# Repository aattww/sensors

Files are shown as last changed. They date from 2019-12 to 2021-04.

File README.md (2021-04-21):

# Summary

This project consists of simple Atmel ATmega328P based nodes utilizing HopeRF LoRa RFM95W/RFM96W radios. Battery-powered nodes measure temperature, humidity and barometric pressure, depending on connected hardware. Externally powered pulse type nodes count pulses from different utility meters and also connect to Kamstrup Multical energy meters. Gateway receives and collects these measurements from the sensor nodes and can be accessed by serial communication using Modbus RTU protocol via either two-wire RS-485 or common 3.3 volt UART. This enables interfacing with many DIY home automation systems such as [Domoticz](https://www.domoticz.com/), [Home Assistant](https://www.home-assistant.io/) and [openHAB](https://www.openhab.org/). Sensors uses custom circuit boards but is programmed with Arduino IDE.



This project is a complete package: it includes both hardware designs and software. *Schematics* contains PCB designs so you can manufacture or order PCBs from a factory and solder the nodes. Software is ready to be uploaded as it is. If you do not want to use the hardware designs provided, you should be able to use, for example, Arduino Pro Minis with protoboards instead. Browse through the .inos and the schematics to find out pin definitions. Remember to take into account battery usage if using Pro Minis or other "full size" Arduinos. Also remember that the components used are mostly 3.3 volt tolerant only, so using a 5 volt Uno requires level shifting.

Skip directly to [Instructions](#instructions), although I strongly recommend reading the whole readme first.

# Table of Contents

* [External requirements](#external-requirements)
  * [Libraries](#libraries)
  * [Hardware package (core)](#hardware-package-core)
* [Gateway](#gateway)
  * [Modbus registers](#modbus-registers)
    * [Gateway specific registers](#gateway-specific-registers)
    * [Battery powered node specific registers](#battery-powered-node-specific-registers)
    * [Pulse node specific registers](#pulse-node-specific-registers)
    * [Pulse node with Kamstrup Multical 602 energy meter specific registers](#pulse-node-with-kamstrup-multical-602-energy-meter-specific-registers)
* [Node types](#node-types)
  * [Battery](#battery)
    * [Supported sensors](#supported-sensors)
  * [Pulse](#pulse)
  * [Pulse with Kamstrup Multical 602 energy meter](#pulse-with-kamstrup-multical-602-energy-meter)
* [Radios](#radios)
* [Schematics and PCB](#schematics-and-pcb)
  * [BOM](#bom)
    * [Gateway / Pulse / Pulse with Kamstrup Multical](#gateway--pulse--pulse-with-kamstrup-multical)
    * [Battery](#battery-1)
  * [LEDs](#leds)
    * [Gateway](#gateway-1)
    * [Battery](#battery-2)
    * [Pulse / Pulse with Kamstrup Multical](#pulse--pulse-with-kamstrup-multical)
  * [Headers, terminals and buttons](#headers-terminals-and-buttons)
    * [Gateway](#gateway-2)
    * [Battery](#battery-3)
    * [Pulse / Pulse with Kamstrup Multical](#pulse--pulse-with-kamstrup-multical-1)
* [Instructions](#instructions)
* [Version history](#version-history)

# External requirements

Sensors requires a few external components to work: libraries provide functions for radio communications and connected sensors while hardware package handles needed fuses to work with custom boards used by Sensors. Follow carefully especially the instructions regarding RadioHead and Cryptography libraries, as these require a couple of underlying changes.

## Libraries

**RadioHead Packet Radio library for embedded microprocessors** provides support for RFM95W/RFM96W radios (and many others as well). Download from [airspayce.com](https://www.airspayce.com/mikem/arduino/RadioHead/). After extracting the library to your Arduino IDE libraries folder you will have to do one adjustment. In the beginning of *RadioHead/RH_RF95.h* change line  
`#define RH_RF95_FIFO_SIZE 255`  
to  
`#define RH_RF95_FIFO_SIZE 64`  
Communication will not work without this change. You also risk running out of SRAM without this adjustment.

**Arduino Cryptography Library** includes support for encryption. If you do not plan to encrypt traffic, you will not need this library. Download from [github.com](https://github.com/rweather/arduinolibs). You will need to download the ZIP and extract contents of *libraries* to your Arduino IDE libraries folder. Also remember to uncomment the following line at the very end of *RadioHead/RadioHead.h* to enable encryption:  
`//#define RH_ENABLE_ENCRYPTION_MODULE`  
You will also need to disable watchdog entropy harvesting by commenting out the following line at the beginning of *Crypto/RNG.cpp* because watchdog timer is already used by battery powered nodes:  
`#define RNG_WATCHDOG 1      // Harvest entropy from watchdog jitter.`  
If you are overwhelmed by all this, you may just want not to enable encryption at all. After all, Sensors is not exactly high security system anyway.

**LowPowerLab SI7021** library is needed to work with Silicon Labs Si7021 temperature and humidity sensor. Download from [github.com](https://github.com/LowPowerLab/SI7021).

**SparkFun BME280 Arduino Library** interfaces with Bosch Sensortech BME280 temperature, humidity and barometric pressure sensor. Documentation at [github.com](https://github.com/sparkfun/SparkFun_BME280_Arduino_Library). Install using Arduino IDE Library Manager.

## Hardware package (core)

Sensors uses a bit different hardware design than regular Arduino boards. For example, battery operated nodes run on internal 1 MHz clock and gateway uses external 8 MHz crystal. They also lack bootloader (although you could use it, hardware just doesn't provide serial pins to burn new firmware using bootloader anyway). Instead, program is flashed using ICSP through ISP header.

You could set the necessary fuses manually but it is considerably easier to just use a ready-made hardware package. MCUdude has a nice core specifically to do this. Download MCUdude's MiniCore from [github.com](https://github.com/MCUdude/MiniCore).

# Gateway

Gateway collects data from nodes and acts as an relay to a [Modbus](https://en.wikipedia.org/wiki/Modbus) network. By using Maxim Integrated MAX3485 RS-485 transceiver gateway can be connected to an existing RS-485 Modbus RTU network as a slave. Omitting the transceiver provides a direct TTL serial port. This can be accessed with, for example, another Arduino board, FTDI chip or connected directly to a Raspberry Pi. Regardless of the physical connection, gateway is accessed using Modbus protocol. Gateway requires regulated 3.3 volts or (unregulated) 5-12 volts DC power supply. In addition, gateway has three pulse inputs (pulse values are periodically saved to EEPROM and restored on power-up), one of which can be used as an NTC thermistor input. These inputs are also accessible via Modbus.

One drawback of Modbus protocol is that a slave can not inform the master of new messages. For this, pulse 2 can be enabled to work as an external interrupt. This pin behaves like an emulated open collector output (external high state voltage is limited to 3.3 volts, however). The pin will be pulled to ground when a message is received either from an *important* node or any node, depending on the gateway settings. After Modbus read has been done, this pin will be set back to high impedance state.

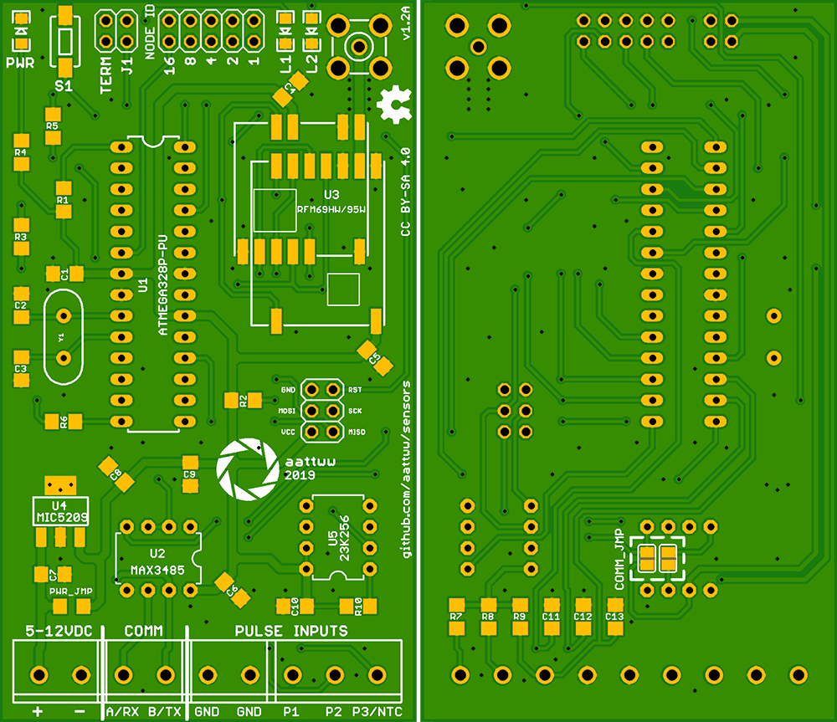
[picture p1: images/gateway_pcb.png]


**Warning:** UART serial port is 3.3 volts, so don't connect it to a 5 volt system.

Why Modbus? Modbus is an easy to use and integrate protocol for this kind of data transfer. Although it is old and somewhat limited in features, it still provides all the necessary things and is widely used in industry. Libraries to access it exist for more or less every platform. Also, most DIY home automation systems ([Home Assistant](https://www.home-assistant.io/), [Domoticz](https://www.domoticz.com/) and [openHAB](https://www.openhab.org/) to name a few) have Modbus support.

## Modbus registers

Registers can be accessed using either function code 3 (read holding registers) or 4 (read input registers). Both return the same register values. Note that registers not defined can not be read. For example, trying to read registers 21-99 or 108-199 will return *illegal data address exception*.

### Gateway specific registers

| Address | Number | Name | Type / Unit | Notes |
| --- | --- | ---- | ---- | ----- |
| 0 | 30001  | Modbus errors (CRC failed or corrupted) | Counter |  |
| 1 | 30002  | Modbus overflown frames | Counter |  |
| 2 | 30003  | Modbus illegal function reads | Counter |  |
| 3 | 30004  | Modbus illegal address reads | Counter |  |
| 4 | 30005 | Modbus frames received | Counter |  |
| 5 | 30006  | Modbus frames sent | Counter |  |
| 6 | 30007  | Nodes during last hour | Counter |  |
| 7 | 30008  | Nodes during last 12 hours | Counter |  |
| 8 | 30009  | Nodes during last 24 hours | Counter |  |
| 9 | 30010  | At least one node low on battery | Boolean |  |
| 10 | 30011  | Gateway out of memory | Boolean |  |
| 11 | 30012  | Gateway uptime | Hour | |
| 12 | 30013  | Firmware version | | 8 MSB = major, 8 LSB = minor |
| 13 | 30014  | Status |  | See below for bits. |
| 14 | 30015  | Pulse 1 | Counter | 32 bit |
| 16 | 30017  | Pulse 2 | Counter | 32 bit |
| 18 | 30019  | Pulse 3 / Temperature | Counter / °C | 32 bit |
| 20 | 30021  | Last received node ID |  |  |

Status register bits (from LSB to MSB):
* Bit 0 **External SRAM:** *1* if gateway has external SRAM, *0* if using internal SRAM. Affects maximum number of nodes, see notes in [Schematics and PCB](#schematics-and-pcb).
* Bit 1-15 **Reserved**

### Battery powered node specific registers

First address is *node id * 100*. For example, this table shows addresses for a node id 1. Similarly, measurements for node id 2 start at address 200, and so on.

| Address | Number | Name | Type / Unit | Notes |
| --- | --- | ---- | ---- | ----- |
| 100 | 30101  | Last received | Minute | When was node last seen. |
| 101 | 30102  | Battery voltage | mV | Current battery voltage. |
| 102 | 30103  | Transmit power | % | Relative transmit power. |
| 103 | 30104  | Transmit interval | Minute | How often the node transmits at least. |
| 104 | 30105  | Header |  | Only 8 LSB, debug data. See below for bits. |
| 105 | 30106  | Temperature | °C | ×10 |
| 106 | 30107  | Relative humidity | RH% | ×10. **Only if node has Si7021 or BME280.** |
| 107 | 30108  | Barometric pressure / Temperature | hPa / °C | ×10. **Pressure if node has BME280, temperature if node has both Si7021 and NTC.** |

Header register bits (from LSB to MSB):
* Bit 0-2 **Node type:** Internal definiton of the node type.
* Bit 3 **Reserved**
* Bit 4 **Battery-powered:** *1* if node is battery-powered, *0* if powered externally.
* Bit 5 **Important:** *1* if node has declared itself important, *0* if not.
* Bit 6-7 **Reserved**

### Pulse node specific registers

First address is *node id * 100*. For example, this table shows addresses for a node id 2. Similarly, measurements for node id 3 start at address 300, and so on.

| Address | Number | Name | Type / Unit | Notes |
| --- | --- | ---- | ---- | ----- |
| 200 | 30201  | Last received | Minute | When was node last seen. |
| 201 | 30202  | Transmit power | % | Relative transmit power. |
| 202 | 30203  | Transmit interval | Minute | How often the node transmits at least. |
| 203 | 30204  | Header |  | Only 8 LSB, debug data. See below for bits. |
| 204 | 30205  | Pulse 1 | Counter | 32 bit |
| 206 | 30207  | Pulse 2 | Counter | 32 bit |
| 208 | 30209  | Pulse 3 / Temperature | Counter / °C | 32 bit |

Header register bits (from LSB to MSB):
* Bit 0-2 **Node type:** Internal definiton of the node type.
* Bit 3 **Reserved**
* Bit 4 **Battery-powered:** *1* if node is battery-powered, *0* if powered externally.
* Bit 5 **Important:** *1* if node has declared itself important, *0* if not.
* Bit 6-7 **Reserved**

### Pulse node with Kamstrup Multical 602 energy meter specific registers

First address is *node id * 100*. For example, this table shows addresses for a node id 3. Similarly, measurements for node id 4 start at address 400, and so on.

| Address | Number | Name | Type / Unit | Notes |
| --- | --- | ---- | ---- | ----- |
| 300 | 30301  | Last received | Minute | When was node last seen. |
| 301 | 30302  | Transmit power | % | Relative transmit power. |
| 302 | 30303  | Transmit interval | Minute | How often the node transmits at least. |
| 303 | 30304  | Header |  | Only 8 LSB, debug data. See below for bits. |
| 304 | 30305  | Pulse 1 | Counter | 32 bit |
| 306 | 30307  | Pulse 2 | Counter | 32 bit |
| 308 | 30309  | Pulse 3 / Temperature | Counter / °C | 32 bit |
| 310 | 30311  | Heat energy | kWh | 32 bit |
| 312 | 30313  | Actual flow | l/h | 32 bit |
| 314 | 30315  | Volume | m³ | ×100. 32 bit |
| 316 | 30317  | Actual power | kW | ×10. 32 bit |
| 318 | 30319  | Actual t₁ | °C | ×100. 32 bit |
| 320 | 30321  | Actual t₂ | °C | ×100. 32 bit |

Header register bits (from LSB to MSB):
* Bit 0-2 **Node type:** Internal definiton of the node type.
* Bit 3 **Reserved**
* Bit 4 **Battery-powered:** *1* if node is battery-powered, *0* if powered externally.
* Bit 5 **Important:** *1* if node has declared itself important, *0* if not.
* Bit 6-7 **Reserved**

# Node types

Sensors includes two main types of nodes: battery and pulse. Battery-powered low-power nodes monitor temperature, humidity and pressure. Pulse type nodes are externally powered and count pulses from utility meters. Pulse nodes also support connecting one NTC thermistor for temperature monitoring and RS-485 Modbus RTU. The latter enables the node to be connected to a Kamstrup Multical 602 energy meter.

## Battery

Battery powered sensors provide simple nodes to monitor temperature, humidity and barometric pressure. These nodes operate on two normal 1.5 volt AA alkaline batteries. If longer lifetime is needed or if node is placed in cold environment, more expensive 1.5 volt AA-size lithium batteries can also be used.

**Warning:** Hardware provides no reverse voltage protection in order to conserve power and to keep number of parts minimal, so **make sure to observe polarity when inserting batteries or you will destroy the node**.

Nodes spend most of the time sleeping, only to wake up to take measurements and send values to gateway. Frequency can be controlled through settings at the beginning of the code file. In threshold mode, nodes wake up periodically and take measurements. If values differ enough from previously sent ones, a message is sent. If not, nodes return to sleep. However, there is a specific force time controlling how often a new message is sent at least regardless of threshold. If a node is not operating in threshold mode, it will send a message every time it wakes up.

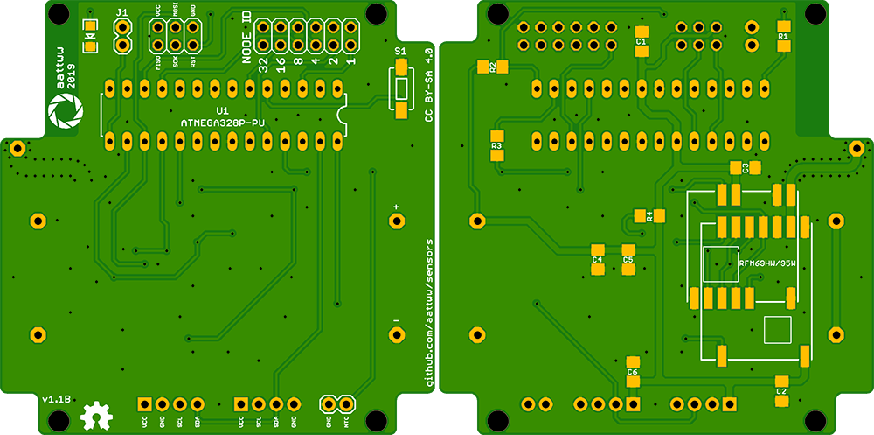
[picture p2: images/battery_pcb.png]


### Supported sensors

Nodes support three types of sensors: Silicon Labs Si7021, Bosch Sensortech BME280, and a common NTC thermistor. The first one has temperature and humidity, the second one adds barometric pressure, and the latter provides only temperature. A node can have only one kind of sensor, or as a special case both Si7021 and NTC at the same time. PCB provides footprints for all, and the exact type is defined in runtime. That is, every node is flashed with the same software and it checks at bootup what kind of sensor configuration is connected.

**Si7021** sensors can be bought as breakout boards from eBay and similar places for a couple of dollars. When buying the sensor, get one that does not include voltage regulator and I2C level shifting. Battery powered nodes operate on 3.3 volts so Si7021 can be fed directly. Not having (unnecessary) regulator saves battery power. For example, [this one](https://www.ebay.com/itm/SMD-MINI-Si7021-Temperature-and-Humidity-Sensor-I2C-Interface-for-Arduino/264394330907) is recommended, while [this one](https://www.ebay.com/itm/Si7021-Industrial-High-Precision-Humidity-Sensor-I2C-Interface-for-Arduino/201539848414) is not.

**BME280** sensors are also available in eBay, Aliexpress and similar as breakout boards. They are a bit more expensive. These seem not to be available without the onboard regulator, so if you want to lower power consumption, your only option is to remove the regulator. Example image of a removed regulator [shown here](images/bme280.jpg). [This sensor](https://www.ebay.com/itm/Breakout-Temperature-Humidity-Barometric-Pressure-BME280-Digital-Sensor-Module/401000227934), for example, has been used successfully.

**Note:** Chinese sellers sometimes mix the BME280 with earlier and less featured BMP280. Be careful when buying the sensor. Info about this for example [here](https://goughlui.com/2018/08/05/note-bosch-sensortec-bmp280-vs-bme280-sensor-confusion/) and [here](https://www.meteocercal.info/forum/Thread-Bosch-Sensortec-BMP280-vs-BME280-Sensor-Confusion).

**NTC thermistors** can be purchased from the same places as the other sensors. When buying thermistors, make sure you get three necessary values: *nominal resistance*, *nominal temperature* and *beta coefficient*. For example, [this thermistor](https://www.ebay.com/itm/5PCS-1m-NTC-Thermistor-accuracy-temperature-sensor-10K-1-3950-Waterproof-Probe/311572298670) has been successfully used and works with the default values.

## Pulse

Pulse type nodes are intended to measure pulses from a water, electricity, gas or other kind of meter with pulse output. Nodes have three pulse inputs, one of which can be used as an NTC thermistor input instead of a pulse input. Pulse inputs are pulled high internally by microcontroller or with optional external resistors, and connected meter pulls it low to ground. Pulse values are periodically saved to EEPROM and restored on power-up. Pulse nodes require either regulated 3.3 volts or (unregulated) 5-12 volts DC power supply. They use the same PCB as the gateway.

## Pulse with Kamstrup Multical 602 energy meter

These nodes are regular pulse nodes with added support for Kamstrup Multical 602 energy meter. Node is connected by RS-485 to a Multical 602 energy meter and periodically reads certain values from the meter. See Modbus register listing above for these values.

**Note:** Multical 602 seems to be discontinued and replaced by Multical 603. According to datasheet, Multical 603 supports the same Modbus registers as the old 602. Therefore nodes should work with newer 603s but this is untested.

**Protip:** Using this node as an example, it should be quite easy to connect some other kind of Modbus RTU capable device to a Pulse type node and adjust code accordingly. This way you can read any other Modbus meters or devices via Sensors nodes.

# Radios

Sensors utilize HopeRF RFM95W and RFM96W LoRa radios. RFM95W is for 868/915 MHz and RFM96W for 433 MHz. These are cheap low power radios with very good range. Battery nodes use wire or helical antennas, while gateway and pulse nodes have SMA connectors for better performing antennas. Please consider local regulations when choosing frequency range, bandwidth, transmit power and other radio related settings. Nodes automatically adjust transmit power to the lowest possible level.

Attainable range depends greatly on numerous things but personally I have easily achieved over one kilometer through a reinforced concrete wall and a metal facade. This was between a gateway with a dipole SMA antenna and a battery node with helical antenna. The same setup also reached over 200 meters through buildings in a more built environment. However, as with wireless communication in general, your results will vary.

**Note:** On the PCB there is footprint for older HopeRF RFM69HW radio as well. It should work, but it has not been tested and there is currently no support in software for this. Feel free to create a new branch and implement it.

# Schematics and PCB

Following is the table of bill of materials. Not all components are needed, see the notes below for these parts. Majority of the SMD components are 1206 package for easier hand soldering. Gateways and pulse nodes share the same PCB.

Some notes:
* MAX3485 transceiver is needed only if you connect the gateway to an existing RS-485 network. If you use direct UART it is not needed. In this case, remember to also short *COMM_JMP* at the bottom.
* External pull-up resistors are probably not needed in most cases as internal ones in ATmega328P are usually adequate. However, if you are connecting NTC thermistor to pulse 3, remember to solder the 10 kOhm series resistor.
* Pulse smoothing capacitors are optional. Use them if you encounter erroneous pulses, ie. too many pulses are counted. For example, I had a [rain gauge](https://www.amazon.co.uk/dp/B00QDMBXUA) connected to a pulse input with a rather long cable (about 10 meters running next to mains power supply for part of length). Extra pulses were counted even when no rain had fallen. Adding a 10 uF capacitor removed these wrong measures.
* MIC5209 regulator makes it possible to power the gateway/pulse node with DC voltage between 5-12 volts (technically up to 16 volts but it might start to get warm). If you can supply the board with regulated 3.3 volts, you can omit the regulator. In this case, also short the *PWR_JMP*.
* The Microchip 23K256 SRAM chip is optional. Without it, gateway falls back using its internal SRAM. However, this severely limits the amount of nodes. With the 23K256 gateway supports 100 nodes regardless of type, without it only 10. This varies by node type, however. For example, without external SRAM gateway supports 10 battery nodes, or 5 pulse nodes, or 6 battery nodes plus 2 pulse nodes.
* SMA connector can be omitted and replaced with a wire or a helical antenna if these smaller gain antennas are sufficient. You can also, with some very careful alignment, solder a u.FL connector on to the SMA connector footprint. This allows using a u.FL to SMA pigtail to move the actual SMA connector away.

I have successfully ordered PCBs from Seeed Studio. You can get boards for 10 gateways/pulse nodes and 10 battery nodes for $9.80 plus postage. Of course any prototype PCB factory will work. PCBs are designed not to have any tight spacings or need for strict tolerances. For gateway and pulse node, select 1.6mm thickness (the enclosure will hold the PCB better). With battery nodes, boards can be thinner (for example 1.2mm works well). Other options should be okay with defaults.

Boards are designed to fit the enclosures mentioned in the table. [Bud Industries DMB-4771](https://www.budind.com/view/Plastic+Boxes/DIN+Rail+Mount+Multi-Board+Box) is a 35mm DIN rail mounted box, while [Supertronic PP42](http://www.supertronic.com/en/cajas_de_plastico/sensors/29/pp42/50) is a simple wall mounted enclosure (use double-sided tape). In the *schematics* folder there is also *AP9_holder.stl* which is a 3D model of a simple holder to fix a battery node into an [ABB AP9 junction box](https://new.abb.com/products/2TKA140012G1/ap9-junction-box-ip65). This is especially handy if you install a node outside and have access to a 3D printer. You will need two holders and a set of small screws. You will also need to have a way to make the box rain-proof but still let humidity and temperature in. Poking some holes into membrane cable entries is one way, or if you want to go professional, use a sintered protective cover. [This](https://www.ebay.com/itm/Protective-Cover-SHT10-SHT20-Soil-Temperature-Humidity-Moisture-Sensor-Shell/173940209491) has been proven to work: a BME280 breakout board will *just* fit inside if you solder wires to the board as [shown here](images/bme280.jpg). Remember to wrap the breakout board (but not the sensor itself) with some insulating tape or use heat shrink to prevent short circuits. [This image](images/si7021_wired.jpg) shows an Si7021 breakout board prepared for outdoor sensor use. You will also need to drill off the plastic inside with the connectors of the protective cover. Use some imagination here. A ready-made weatherproofed sensor looks something like [this](images/weatherproof_node.jpg). Connecting an NTC thermistor with sufficiently long wire will make a nice water temperature node as shown [here](images/water_temperature_node.jpg).

## BOM

### Gateway / Pulse / Pulse with Kamstrup Multical

| Part | Value | Device | Package | Type | Notes |
| ---- | ----- | --- | --- | ---- | ----- |
| C1 | 100 nF | Decoupling capacitor | 1206 | Ceramic | |
| C2 | 22 pF | Crystal capacitor | 1206 | Ceramic | |
| C3 | 22 pF | Crystal capacitor | 1206 | Ceramic | |
| C4 | 100 nF | Decoupling capacitor | 1206 | Ceramic | Used only with RFM95W / RFM96W. |
| C5 | 100 nF | Decoupling capacitor | 1206 | Ceramic | Used only with RFM69HW. |
| C6 | 100 nF | Decoupling capacitor | 1206 | Ceramic | Used only with U2 (MAX3485). |
| C7 | 1 uF | Power input capacitor | 1206 | Tantalum | |
| C8 | 1 uF | Power output capacitor | 1206 | Tantalum | |
| C9 | 10 uF | Power output capacitor | 1206 | Ceramic | |
| C10 | 100 nF | Decoupling capacitor | 1206 | Ceramic | Used only with 23K256. |
| C11 | Depends | Pulse 3 smoothing capacitor | 1206 | Ceramic | Use if erroneous pulses are counted. |
| C12 | Depends | Pulse 2 smoothing capacitor | 1206 | Ceramic | Use if erroneous pulses are counted. |
| C13 | Depends | Pulse 1 smoothing capacitor | 1206 | Ceramic | Use if erroneous pulses are counted. |
| R1 | 10 kOhm | Reset pull-up resistor | 1206 | | |
| R2 | 10 kOhm | Radio slave select pull-up resistor | 1206 | | |
| R3 | 120 Ohm | RS-485 termination resistor | 1206 | | Used only with U2 (MAX3485). |
| R4 | Depends | Power LED resistor | 1206 | | Select value based on LED in use. |
| R5 | Depends | Activity LED resistor | 1206 | | Select value based on LED in use. |
| R6 | Depends | Serial activity LED resistor | 1206 | | Select value based on LED in use. |
| R7 | Depends / 10 kOhm | Pulse 3 pull-up / NTC series resistor | 1206 | | Use if ATmega328P internal pull-up resistor is not strong enough, or NTC is to be used. |
| R8 | Depends | Pulse 2 pull-up resistor | 1206 | | Use if ATmega328P internal pull-up resistor is not strong enough. |
| R9 | Depends | Pulse 1 pull-up resistor | 1206 | | Use if ATmega328P internal pull-up resistor is not strong enough. |
| R10 | 10 kOhm | SRAM slave select pull-up resistor | 1206 | | Used only with 23K256. |
| D1 | | Serial activity LED | 1206 | | |
| D2 | | Power LED | 1206 | | |
| D3 | | Activity LED | 1206 | | |
| Y1 | 8 MHz | HC-49US 8 MHz crystal | | | |
| S1 | | Momentary push button | 3x6 mm | | For example, [this one](https://www.ebay.com/itm/100-Pcs-3x6x2-5mm-Momentary-Tact-SMD-SMT-Push-Button-Micro-Switch-2-Pin/272961316148). |
| X1 | | SMA connector | | | For example, [this one](https://www.ebay.com/itm/End-Launch-PCB-Mount-SMA-Female-Plug-Straight-RF-Connector-Adapter-10-Pcs-R7Z6-/253508669169). |
| Header | | ISP programming header | 2x3, 0.1" pitch | | |
| Header | | Node ID selection header | 2x5, 0.1" pitch | | |
| Header | | RS-485 terminate and J1 header | 2x2, 0.1" pitch | | |
| Screw terminals | | Power, serial, pulse grounds, pulse inputs | 3x2 + 1x3, 5.08mm pitch | | For example, [two terminal](https://www.ebay.com/itm/20PCS-KF301-2P-2-Pin-Plug-in-Terminal-Block-Connector-5-08mm-Pitch-Through-Hole/381374540897) and [three terminal](https://www.ebay.com/itm/10pcs-KF301-3P-5-08mm-Blue-Connect-Terminal-Blue-Screw-Terminal-Connector/201415082308). |
| PWR_JMP | | Solder jumper | 1206 | | Short or use a zero-ohm resistor if not using U4, i.e. board is provided external regulated 3.3 volts. |
| COMM_JMP | | Solder jumper | | | Short if not using U2, i.e. direct UART is used. |
| U1 | | Atmel ATmega328P microcontroller | DIP-28 | | Preferably use a socket. |
| U2 | | Maxim MAX3485 RS-485 transceiver | DIP-8 | | Preferably use a socket. Use only if connected to an RS-485 network. |
| U3 | | HopeRF RFM95W/RFM96W/RFM69HW | | | |
| U4 | | Microchip MIC5209-3.3 regulator | SOT-223 | | Optional (see notes above). |
| U5 | | Microchip 23K256 SRAM | DIP-8 | | Optional (see notes above). Preferably use a socket. |
| Enclosure | | Bud Industries DMB-4771 | | | |

### Battery

| Part | Value | Device | Package | Type | Notes |
| ---- | ----- | --- | --- | ---- | ----- |
| C1 | 100 nF | Decoupling capacitor | 1206 | Ceramic | |
| C2 | 100 nF | Decoupling capacitor | 1206 | Ceramic | Used only with RFM69HW. |
| C3 | 100 nF | Decoupling capacitor | 1206 | Ceramic | Used only with RFM95W / RFM96W. |
| C4 | 100 nF | Power smoothing capacitor | 1206 | Ceramic | |
| C5 | 10 uF | Power smoothing capacitor | 1206 | Ceramic | |
| C6 | 100 nF | Decoupling capacitor | 1206 | Ceramic | |
| R1 | Depends | Activity LED resistor | 1206 | | Select value based on LED in use. |
| R2 | 10 kOhm | Reset pull-up resistor | 1206 | | |
| R3 | 10 kOhm | NTC series resistor | 1206 | | Use only with NTC. |
| R4 | 10 kOhm | Radio slave select pull-up resistor | 1206 | | |
| D1 | | Activity LED | 1206 | | |
| S1 | | Momentary push button | 3x6 mm | | For example, [this one](https://www.ebay.com/itm/100-Pcs-3x6x2-5mm-Momentary-Tact-SMD-SMT-Push-Button-Micro-Switch-2-Pin/272961316148). |
| Antenna | | Antenna for frequency in use, helical or wire | | | For example, [this one](https://www.ebay.com/itm/10PCS-868MHz-Helical-Antenna-2-15dBi-13mm-HPD215T-B-868MHZ-Stable-Remote-Contorl/311598709972). |
| Header | | ISP programming header | 2x3, 0.1" pitch | | |
| Header | | Node ID selection header | 2x6, 0.1" pitch | | |
| Header | | J1 header | 1x2, 0.1" pitch | | |
| U1 | | Atmel ATmega328P microcontroller | DIP-28 | | Preferably use a socket. |
| U2 / U3 | | Si7021 / BME280 sensor | | | Two footprints for different pin orders. See [Supported sensors](#supported-sensors) for more info. |
| U4 | | HopeRF RFM95W/RFM96W/RFM69HW | | | |
| NTC | | NTC thermistor | | | Header provided. See [Supported sensors](#supported-sensors) for more info. |
| Battery holder | | Holder for two AA size batteries | | | For example, a pair of [these](https://www.ebay.com/itm/AA-1-5V-PP3-Battery-or-Open-with-Switch-Holder-AA-x-1-Holder-PCB-Amount-5-C6T2-/283528370571). |
| Enclosure | | Supertronic PP42 | | | |

## LEDs

Boards have a few onboard LEDs to indicate different events. This chapter describes these events. All boards will blink the current running firmware version after power-up.

### Gateway

*PWR* is lit whenever gateway is powered. *L2* blinks when gateway is transmitting in Modbus network. The following table concerns *L1*.

| Blinks | Interval | Description | During | Notes |
| --- | --- | --- | --- | ----- |
| 1 | 2 sec. | Illegal ID set. | Startup | Check ID headers and reboot. |
| 5 | 2 sec. | Failed to initialize radio. | Startup | Check connections. |
| 1 | - | Received and saved a message from a node. | Operation |  |
| 2 | - | Received a message from a node but memory is full. | Operation | Add external SRAM or lower amount of nodes. |
| 3 | - | Successful Modbus read from master. | Operation |  |
| 4 | - | Failed Modbus read from master. | Operation |  |

### Battery

Battery nodes have only one LED.

| Blinks | Interval | Description | During | Notes |
| --- | --- | --- | --- | ----- |
| 1 | 2 sec. | Illegal ID set. | Startup | Check ID headers and reboot. |
| 3 | 2 sec. | Failed to initialize a proper sensor configuration. | Startup | Check connections. |
| 5 | 2 sec. | Failed to initialize radio. | Startup | Check connections. |
| 1 | - | Successful transmit. | Operation | Only in debug mode or forced transmit. |
| 2 | - | Failed transmit. | Operation | Only in debug mode or forced transmit. |

### Pulse / Pulse with Kamstrup Multical

Pulse nodes share the same board as gateway so they also have three LEDs. *PWR* is lit whenever node is powered. *L2* blinks when node is transmitting in Modbus network. The following table concerns *L1*. Unlike in battery nodes, in pulse nodes *L1* blinks always as they are not limited by battery.

| Blinks | Interval | Description | During | Notes |
| --- | --- | --- | --- | ----- |
| 1 | 2 sec. | Illegal ID set. | Startup | Check ID headers and reboot. |
| 5 | 2 sec. | Failed to initialize radio. | Startup | Check connections. |
| 1 | - | Successful transmit. | Operation |  |
| 2 | - | Failed transmit. | Operation |  |
| 3 | - | Successful Modbus read. | Operation |  |
| 4 | - | Failed Modbus read. | Operation |  |

## Headers, terminals and buttons

Boards have a couple of user settable headers. These need to be set before boards are powered. Each device also has one button. In addition, gateway and pulse nodes have screw terminals for power, serial communications and pulse inputs.

### Gateway

#### Headers

* **TERM** is 120 Ohm RS-485 termination resistor. Short if the gateway is in the very end of a long RS-485 line.
* **J1** is currently not in normal use. See below for clearing old pulse values from EEPROM.
* **NODE ID** sets 5 bit Modbus slave address.

#### Button

Button in gateway is currently not in use in normal operation. However, if you short **J1** and hold the button while powering on the gateway, saved pulse values in EEPROM will be set to zero.

#### Terminals

* **+** and **-** are the 5-12 volts DC power inputs.
* **A/RX** and **B/TX** are UART/RS-485 serial terminals.
* Two **GND**s can be used as grounds for pulse inputs.
* **P1** is the pulse 1 input.
* **P2** is the pulse 2 input or external interrupt output (active low open drain), depending on the settings.
* **P3/NTC** is the pulse 3 input or NTC thermistor input, depending on the settings.

### Battery

#### Headers

* **J1** marks a node *important*. When a node declares itself important to gateway, the gateway sets external interrupt pin to inform upstream device of received messages from important nodes.
* **NODE ID** sets 6 bit address in radio network. Every node has to have a unique address.

#### Button

If button is pressed while applying power, a node is put into *debug mode*. In this mode, the node sends new values every 8 seconds and also blinks the LED indicating success. Do not use in long-term as this will drain batteries quickly. Power cycle the node to cancel debug mode.

During normal operation button triggers instant send with full power and blinks the LED indicating success. Use to quickly test if the node is within gateway's range.

### Pulse / Pulse with Kamstrup Multical

#### Headers

* **TERM** is 120 Ohm RS-485 termination resistor. Short if the node is in the very end of a long RS-485 line.
* **J1** marks a node *important*. When a node declares itself important to gateway, the gateway sets external interrupt pin to inform upstream device of received messages from important nodes.
* **NODE ID** sets 5 bit address in radio network. Every node has to have a unique address.

#### Button

If button is pressed while applying power, a node is put into *debug mode*. In this mode, the node sends new values every 8 seconds. Do not use in long-term as this will unnecessarily congest radio network.

During normal operation button triggers instant send with full power. Use to quickly test if the node is within gateway's range. In addition, if you short **J1** and hold the button while powering on the node, saved pulse values in EEPROM will be set to zero.

#### Terminals

* **+** and **-** are the 5-12 volts DC power inputs.
* **A/RX** and **B/TX** are UART/RS-485 serial terminals.
* Two **GND**s can be used as grounds for pulse inputs.
* **P1** is the pulse 1 input.
* **P2** is the pulse 2 input.
* **P3/NTC** is the pulse 3 input or NTC thermistor input, depending on the settings.

# Instructions

## 1. Solder boards

Refer to [Schematics and PCB](#schematics-and-pcb) for detailed instructions and ideas for manufacturing boards. All the chips are through hole packages for easier hand soldering. Smaller components are mostly SMD but they are sufficiently large so that even unexperienced solderers should be able to hand solder them.

## 2. Download this repository

Download the repository. Place the contents of *libraries* to your Arduino libraries folder. Also copy *SensorsGateway*, *SensorsBattery* and *SensorsPulse* folders to your Arduino sketchbook.

## 3. Install hardware package

You can easily install *MiniCore* using *Boards Manager* in Arduino IDE. Follow instructions on [MiniCore's page](https://github.com/MCUdude/MiniCore#how-to-install).

## 4. Install external libraries

Install all the necessary external libraries. Refer to [Libraries](#libraries) section to further instructions. Pay extra attention to the part regarding cryptographic library if you are using encryption.

## 5. Adjust settings

In the beginning of each .ino there is a section containing all the necessary settings with good explanations. Adjust the settings as needed. Remember that frequency, encryption key and low rate have to match on every device in the same network or communication will not work.

## 6. Burn fuses

Since Sensors uses very different hardware than ordinary Arduino boards, microcontrollers have to be programmed with some special settings. To do this, you will need an external AVR ISP programmer. Luckily, you can also use another Arduino (Uno or Pro Mini, for example) if you don't have a dedicated ISP programmer available. Follow instructions at [Arduino.cc](https://www.arduino.cc/en/tutorial/arduinoISP) for wiring and burning the ArduinoISP sketch. There is just one catch: whatever you use to program a new board **has to be 3.3 volts**. ATmega328P is fine with 5 volts, but all other components work at 3.3 volts so supplying the board with 5 volts will most likely burn some or all components. What I suggest is a 3.3 volt version of Arduino Pro Mini or Pro Micro.

Follow the previously mentioned instructions until you hit *Program the bootloader*. In *Tools > Board* and under *MiniCore* select *ATmega328*. Select other options as follows:
* Clock: *1 MHz internal* for battery node, *8 MHz external* for all others
* BOD: *1.8v* for battery node, *2.7v* for others
* Variant: *328P / 328PA*
* Compiler LTO: *LTO enabled*
* Bootloader: *No bootloader*
* Port: Serial port where the programmer Arduino is connected to
* Programmer: *Arduino as ISP*

Next, hit *Burn Bootloader*. This doesn't actually burn any bootloader since we selected not to use a bootloader, it will only burn the necessary fuses. Keep the two boards still connected since next we will upload the sketch.

> **Note:** This has to be done only once with every new microcontroller. If you later change sketch settings and upload the new sketch, you can skip step 6 and follow directly step 7.

## 7. Uploading code

With still the two boards connected, Arduino IDE board settings as described in step 6 and the actual sketch open, just hit *Upload Using Programmer* under *Sketch*. This will upload the sketch like any other Arduino sketch. After this, you are done.

## 8. Place the sensors

Place your gateway to a central location and connect it to a Modbus capable network. Using the jumper headers, set its Modbus slave address and apply power.

Distribute other nodes as needed, selecting first their addresses with jumper headers and then connecting external power or batteries. Use the button on the nodes to force a transmit with full power - normally nodes adjust their transmit power automatically to the lowest possible level. One blink of the onboard LED indicates a successful transmit, two blinks a failed one. LED blinks only when forcing a transmit with the button. You can use the provided Python script [*read_modbus.py*](read_modbus.py) to read data from the gateway for debugging purposes.

Start logging measurements to a MySQL database ([*save_modbus_to_db.py*](save_modbus_to_db.py) provides a starting point for this), for example, and graph it with [Grafana](https://grafana.com/), or connect the gateway to a home automation hub and monitor measurements that way.

# Version history

## v2.1.0 (2021-04-21)

* Added ability to set addresses in settings instead of using headers. This decreases components to be soldered and makes it easier to use Unos, Pro Minis or other full size Arduinos.
* Changed topology image to reflect new PCB shape.

## v2.0.0 (2021-01-09)

* Changed the way how automatic transmit power control works: now it targets a certain user settable RSSI instead of lowering power until transmits fail. See node settings for more info.
* Changed acknowledgements from gateway to nodes. This enables the changed power control method and gives more options in the future.
* Updated example scripts [*save_modbus_to_db.py*](save_modbus_to_db.py) and [*read_modbus.py*](read_modbus.py) to reflect changes made in underlying libraries and to make them easier to use.
* Added a script [*check_alarms.py*](check_alarms.py) as an example on how to send email alerts under different conditions.

**Note:** Due to the changes, version 2 gateway is no longer compatible with nodes running lower versions. Messages will be delivered but because nodes expect different kind of acknowledgements, they will consider messages lost. This triggers retransmits, full transmit power and more battery usage.

## v1.1.3 (2020-10-14)

* Fixed number of last seen nodes zeroing after 2^16 minutes. [#12](https://github.com/aattww/sensors/issues/12)

## v1.1.2 (2020-06-07)

* Fixed 23K256 SRAM handler transactions. [#8](https://github.com/aattww/sensors/issues/8)
* Fixed initial transmit power of battery and pulse type nodes.
* Fixed RFM95W transmit powers to address changes made in the RadioHead library.

## v1.1.1 (2020-03-31)

* Fix and refine NTC sensor reading and calculations in NTCSensor.
* Fixed a possible memory allocation error in SensorsSRAMHandler.
* Update GPL to version 3 and bump copyright years to 2020.

## v1.1.0 (2020-02-15)

* Pulse 2 in gateways can be configured as an external interrupt (active low open drain) which informs upstream device of a new message. See gateway settings for more information.
* Battery and pulse nodes have a new *important* mode set by the jumper **J1**. Setting this mode will trigger gateway to set external interrupt when an *important* node sends new messages.
* ID of the last received node added to gateway Modbus registers.
* Changed some button and header functions. See [Headers, terminals and buttons](#headers-terminals-and-buttons).

## v1.0.2 (2020-02-04)

* Fixed overflow bug in gateway uptime calculation after 45 days.
* Added image of a wired Si7021 breakout board.

## v1.0.1 (2019-12-29)

* Fixed a bug in NTCSensor library where enable pin was controlled even though it was not in actual use, possibly interfering with serial communication.

## v1.0.0 (2019-12-26)

Initial public release.

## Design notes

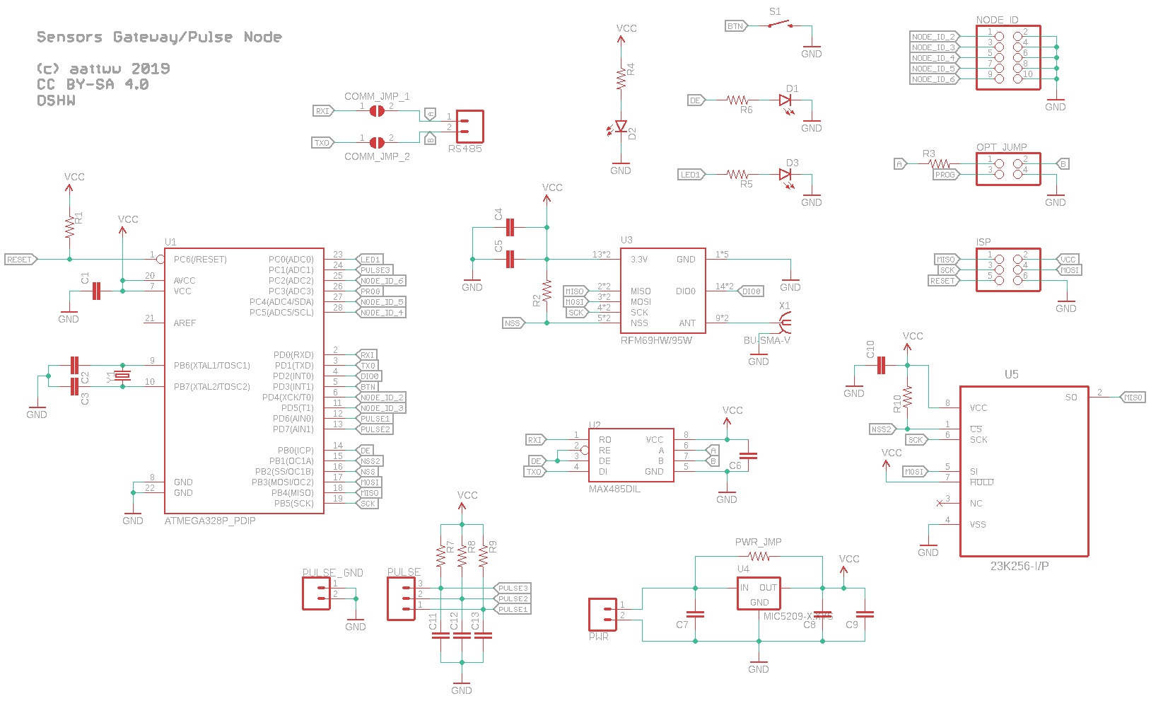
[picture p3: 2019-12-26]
schematics/gateway_schematic.png

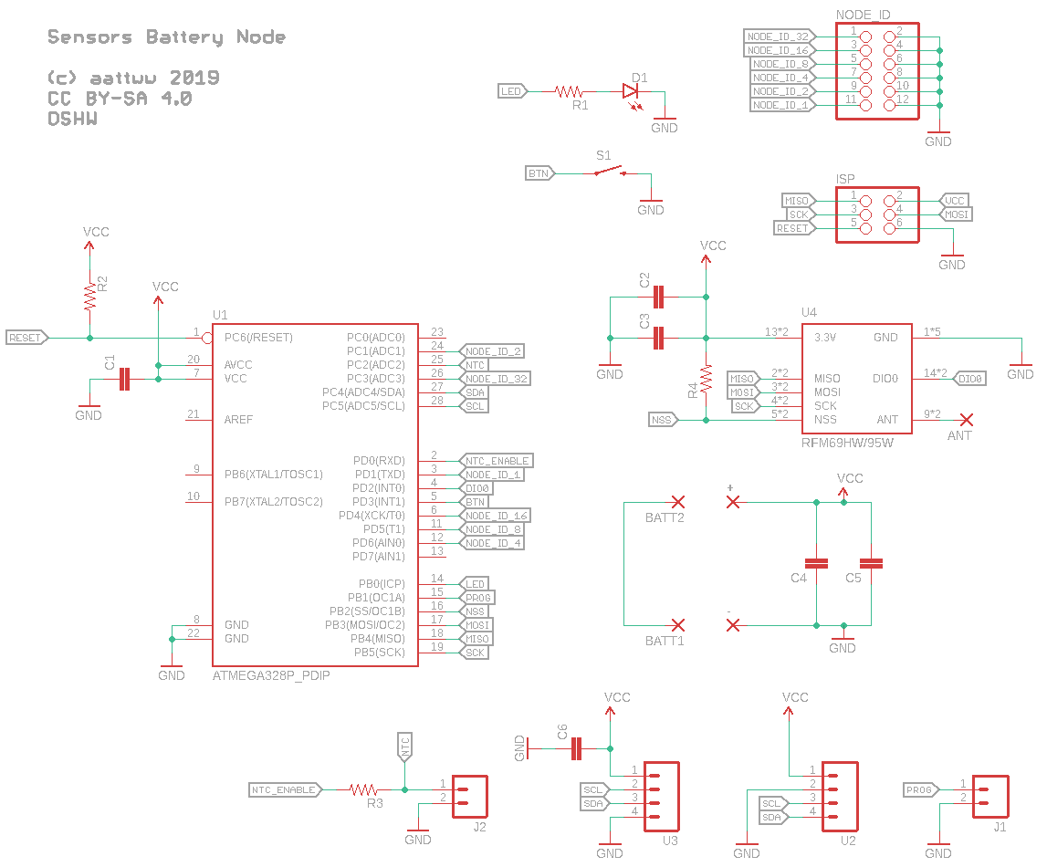
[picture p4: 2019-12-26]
schematics/battery_schematic.png

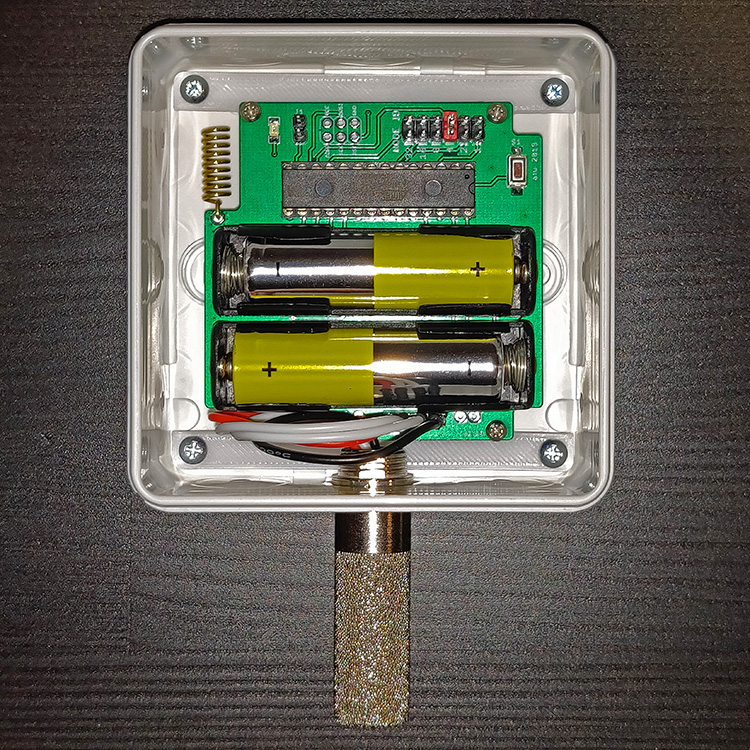
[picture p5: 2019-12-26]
images/weatherproof_node.jpg

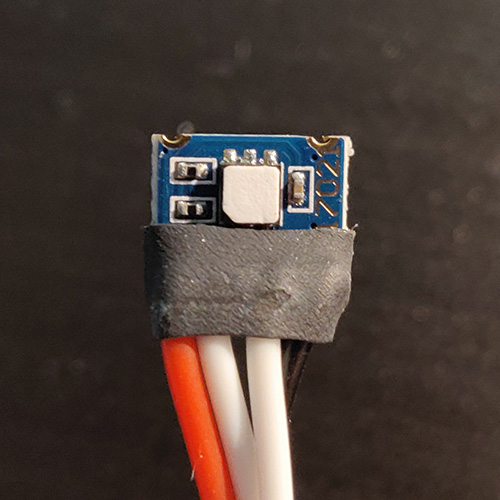
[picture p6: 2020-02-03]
images/si7021_wired.jpg

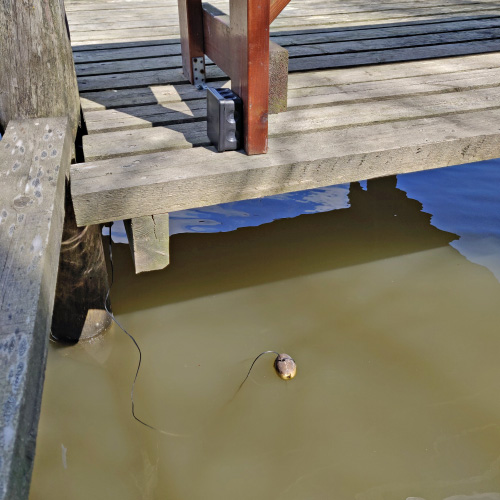
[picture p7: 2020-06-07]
images/water_temperature_node.jpg

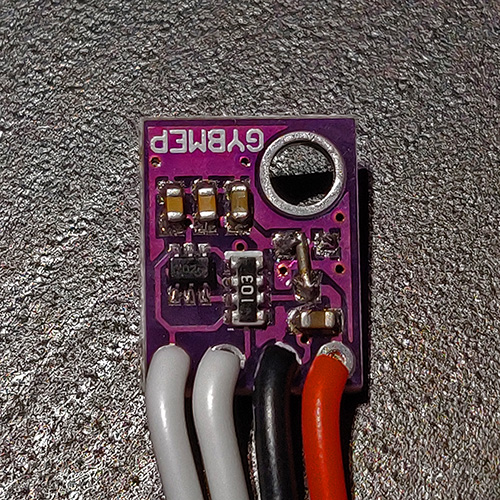
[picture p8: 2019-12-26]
images/bme280.jpg

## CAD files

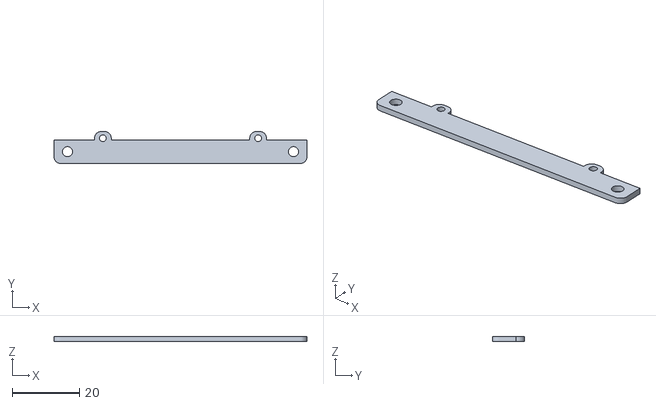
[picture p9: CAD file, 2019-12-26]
schematics/AP9_holder.stl
75.0 x 9.50 x 1.50

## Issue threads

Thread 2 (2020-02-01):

Add interrupt/new message pin to gateway

aattww, 2020-02-01:
Currently because of the way Modbus works, gateway can not inform upstream device of a new message. Add a pin (use one of the pulse inputs in the current hardware version) that can be used to indicate connected upstream device when a new message is received.

Also add an "importance" bit in node's header; node can set this bit to indicate an important change and/or node. This will trigger gateway to set external interrupt pin.

Closed 2020-02-15.

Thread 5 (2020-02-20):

Possible division by zero error in NTCSensor

aattww, 2020-02-20:
https://github.com/aattww/sensors/blob/9c22916e821eb29f9cdcc15228e4839ce89667f8/libraries/NTCSensor/NTCSensor.cpp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

Having shorted thermistor is handled but having not a thermistor at all results in pulling analog in to VCC and counted as 1023. This in turn will result in division by zero in line 197 in NTCSensor.cpp.

aattww, 2020-03-31:
Fixed in #6

Closed 2020-03-31.

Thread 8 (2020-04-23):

23K256 SRAM handler missing transactions

aattww, 2020-04-23:
Currently the SRAM handler does not use beginTransacation() and endTransaction() when communicating SPI. If radio module interrupts SRAM transmission, data might get corrupted.

Closed 2020-06-07.

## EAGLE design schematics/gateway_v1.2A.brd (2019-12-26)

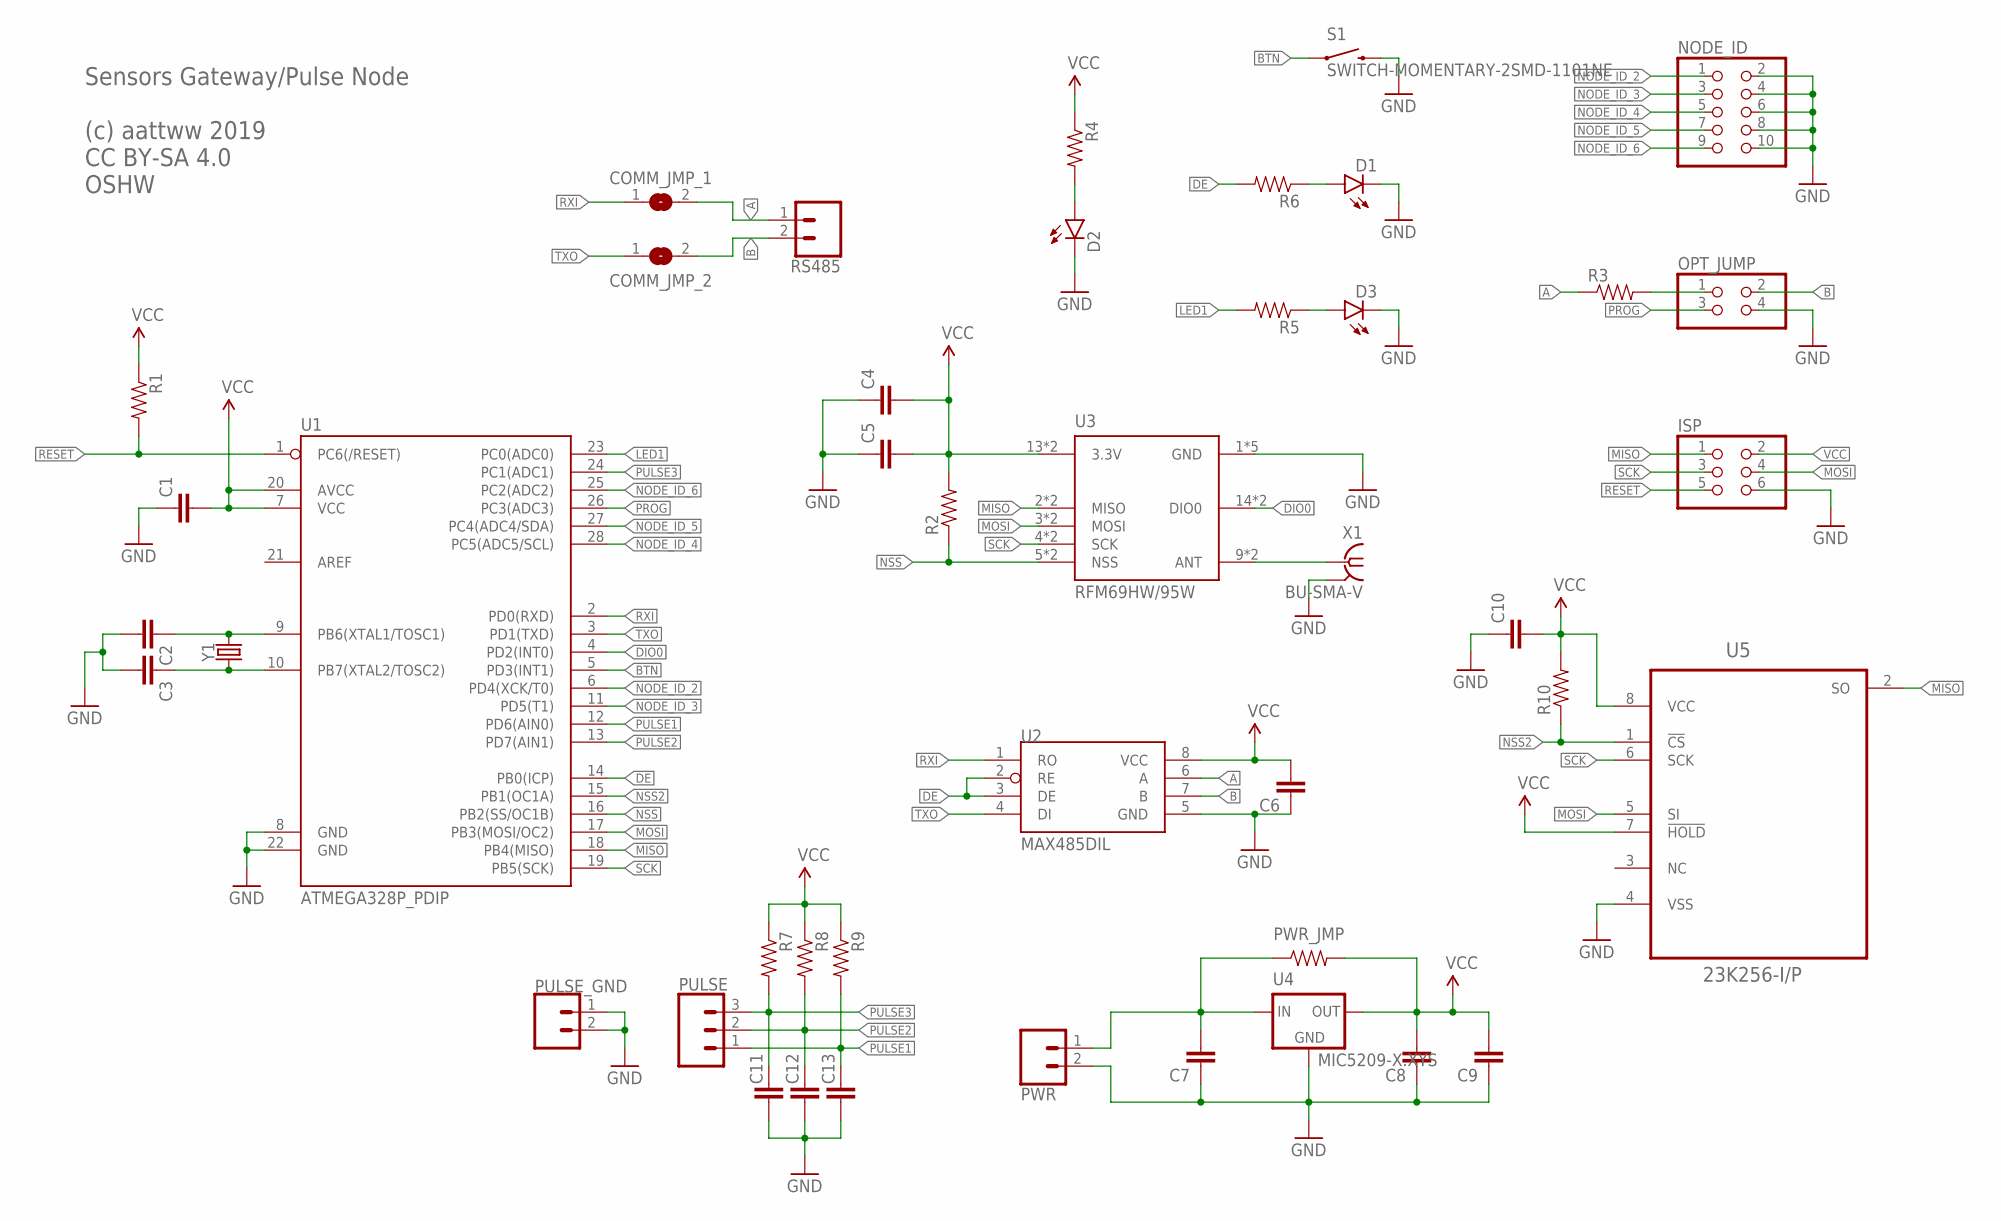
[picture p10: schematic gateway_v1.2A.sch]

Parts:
C1, C2, C3, C4, C5, C6, C7, C8, C9, C10, C11, C12, C13: CAP1206; 1206
COMM_JMP_1, COMM_JMP_2: SJ
D1, D2, D3: LED1206; LED-1206
ISP: PINHD-2X3; 2X03
NODE_ID: PINHD-2X5; 2X05
OPT_JUMP: PINHD-2X2; 2X02
PULSE: CONN_03-SCREW-5MM; SCREWTERMINAL-5MM-3
PULSE_GND: CONN_025MM; SCREWTERMINAL-5MM-2
PWR: CONN_025MM; SCREWTERMINAL-5MM-2
PWR_JMP: RESISTOR1206; 1206
R1, R2, R3, R4, R5, R6, R7, R8, R9, R10: RESISTOR1206; 1206
RS485: CONN_025MM; SCREWTERMINAL-5MM-2
S1: SWITCH-MOMENTARY-2SMD-1101NE; TACTILE-SWITCH-1101NE
U1: ATMEGA328P_PDIP; DIL28-3
U2: MAX485DIL; DIL08
U3: RFM69HW/95W
U4: MIC5209-X.XYS; SOT223
U5: 23K256-I/P; DIP254P762X533-8
X1: BU-SMA-V
Y1: CRYSTALPTH-HC49US; HC49US

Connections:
A: COMM_JMP_1.2, R3.1, RS485.1, U2.6 (A)
B: COMM_JMP_2.2, OPT_JUMP.2, RS485.2, U2.7 (B)
BTN: S1.1, U1.5 (PD3(INT1))
DE: R6.2, U1.14 (PB0(ICP)), U2.2 (RE), U2.3 (DE)
DIO0: U1.4 (PD2(INT0)), U3.14 (DIO0), U3.22 (DIO0)
GND: C1.1, C2.2, C3.2, C4.1, C5.1, C6.1, C7.1, C8.1, C9.1, C10.1, C11.2, C12.2, C13.2, D1.C, D2.C, D3.C, ISP.6, NODE_ID.2, NODE_ID.4, NODE_ID.6, NODE_ID.8, NODE_ID.10, OPT_JUMP.4, PULSE_GND.1, PULSE_GND.2, PWR.2, S1.2, U1.8 (GND), U1.22 (GND), U2.5 (GND), U3.1 (GND), U3.8 (GND), U3.10 (GND), U3.29 (GND), U3.31 (GND), U4.2 (GND), U4.4 (GND), U5.4 (VSS), X1.2, X1.3 (2), X1.4 (2), X1.5 (2)
LED1: R5.2, U1.23 (PC0(ADC0))
MISO: ISP.1, U1.18 (PB4(MISO)), U3.2 (MISO), U3.33 (MISO), U5.2 (SO)
MOSI: ISP.4, U1.17 (PB3(MOSI/OC2)), U3.3 (MOSI), U3.34 (MOSI), U5.5 (SI)
unnamed: U3.9 (ANT), U3.30 (ANT), X1.1
unnamed: OPT_JUMP.1, R3.2
unnamed: C2.1, U1.9 (PB6(XTAL1/TOSC1)), Y1.2
unnamed: C3.1, U1.10 (PB7(XTAL2/TOSC2)), Y1.1
unnamed: D2.A, R4.2
unnamed: D1.A, R6.1
unnamed: D3.A, R5.1
unnamed: C7.2, PWR.1, PWR_JMP.1, U4.1 (IN)
NODE_ID_2: NODE_ID.1, U1.6 (PD4(XCK/T0))
NODE_ID_3: NODE_ID.3, U1.11 (PD5(T1))
NODE_ID_4: NODE_ID.5, U1.28 (PC5(ADC5/SCL))
NODE_ID_5: NODE_ID.7, U1.27 (PC4(ADC4/SDA))
NODE_ID_6: NODE_ID.9, U1.25 (PC2(ADC2))
NSS: R2.1, U1.16 (PB2(SS/OC1B)), U3.5 (NSS), U3.35 (NSS)
NSS2: R10.1, U1.15 (PB1(OC1A)), U5.1 (!CS)
PROG: OPT_JUMP.3, U1.26 (PC3(ADC3))
PULSE1: C13.1, PULSE.1, R9.2, U1.12 (PD6(AIN0))
PULSE2: C12.1, PULSE.2, R8.2, U1.13 (PD7(AIN1))
PULSE3: C11.1, PULSE.3, R7.2, U1.24 (PC1(ADC1))
RESET: ISP.5, R1.2, U1.1 (PC6(/RESET))
RXI: COMM_JMP_1.1, U1.2 (PD0(RXD)), U2.1 (RO)
SCK: ISP.3, U1.19 (PB5(SCK)), U3.4 (SCK), U3.32 (SCK), U5.6 (SCK)
TXO: COMM_JMP_2.1, U1.3 (PD1(TXD)), U2.4 (DI)
VCC: C1.2, C4.2, C5.2, C6.2, C8.2, C9.2, C10.2, ISP.2, PWR_JMP.2, R1.1, R2.2, R4.1, R7.1, R8.1, R9.1, R10.2, U1.7 (VCC), U1.20 (AVCC), U2.8 (VCC), U3.13 (3.3V), U3.28 (3.3V), U4.3 (OUT), U5.7 (!HOLD!), U5.8 (VCC)

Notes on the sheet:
Sensors Gateway/Pulse Node (c) aattww 2019 CC BY-SA 4.0 OSHW

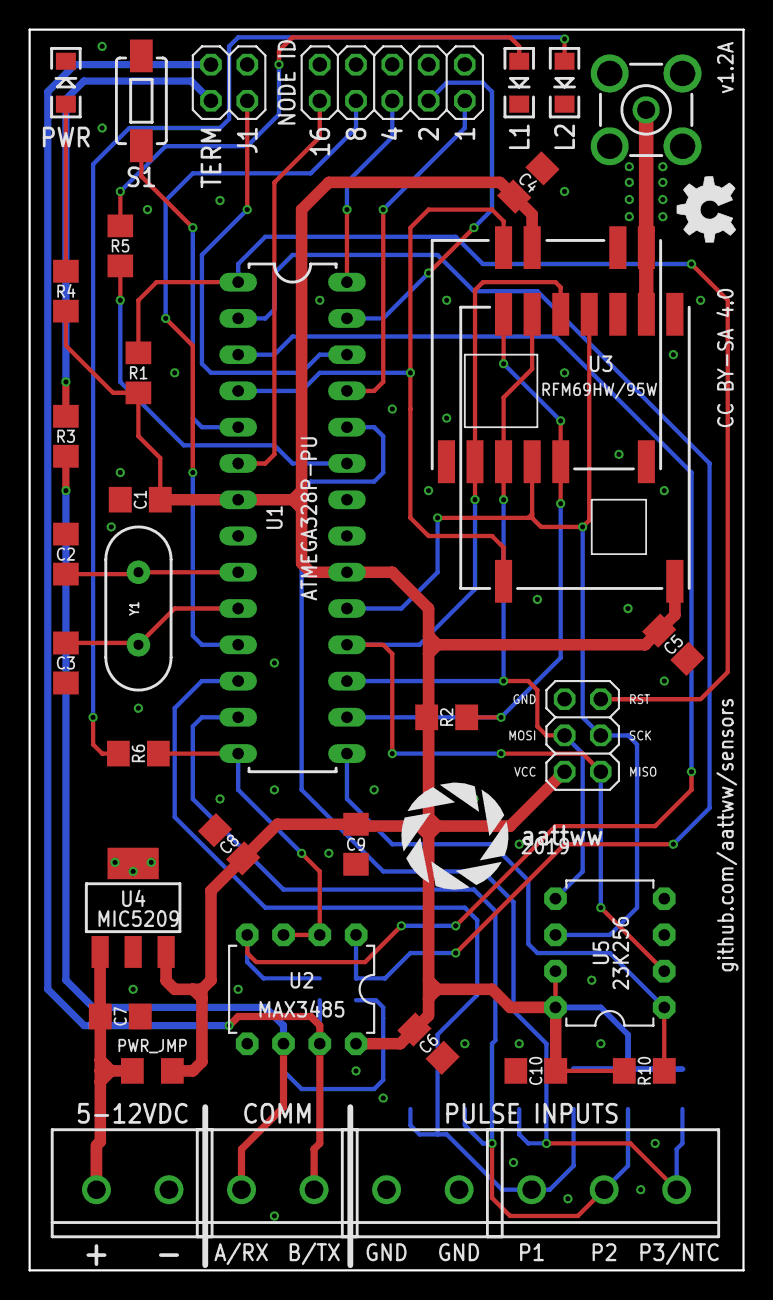
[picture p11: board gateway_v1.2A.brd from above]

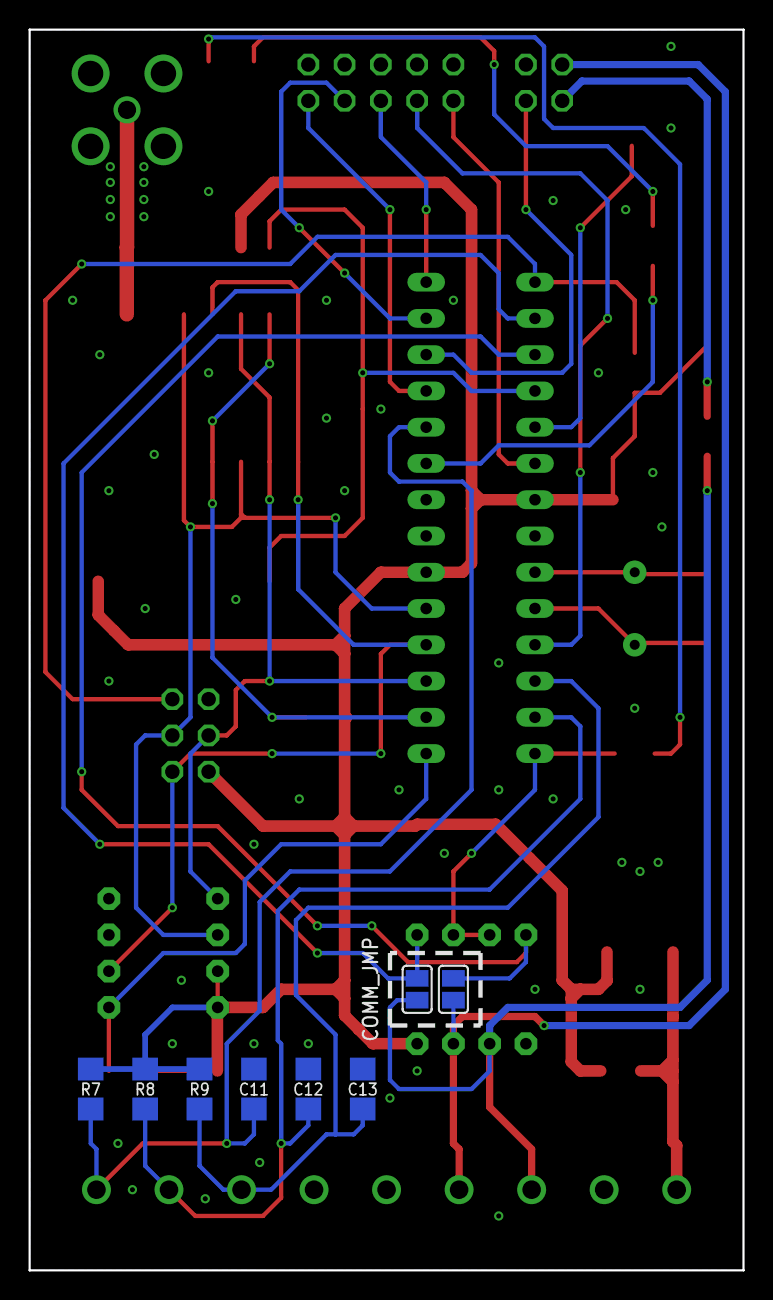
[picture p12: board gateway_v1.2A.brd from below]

Board: 2 copper layers, 50.0 x 86.9 mm, 46 parts (8 on the bottom side), 33 nets.

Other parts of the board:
U$1: OSHW_5MM
U$3: LOGO_7.5MM

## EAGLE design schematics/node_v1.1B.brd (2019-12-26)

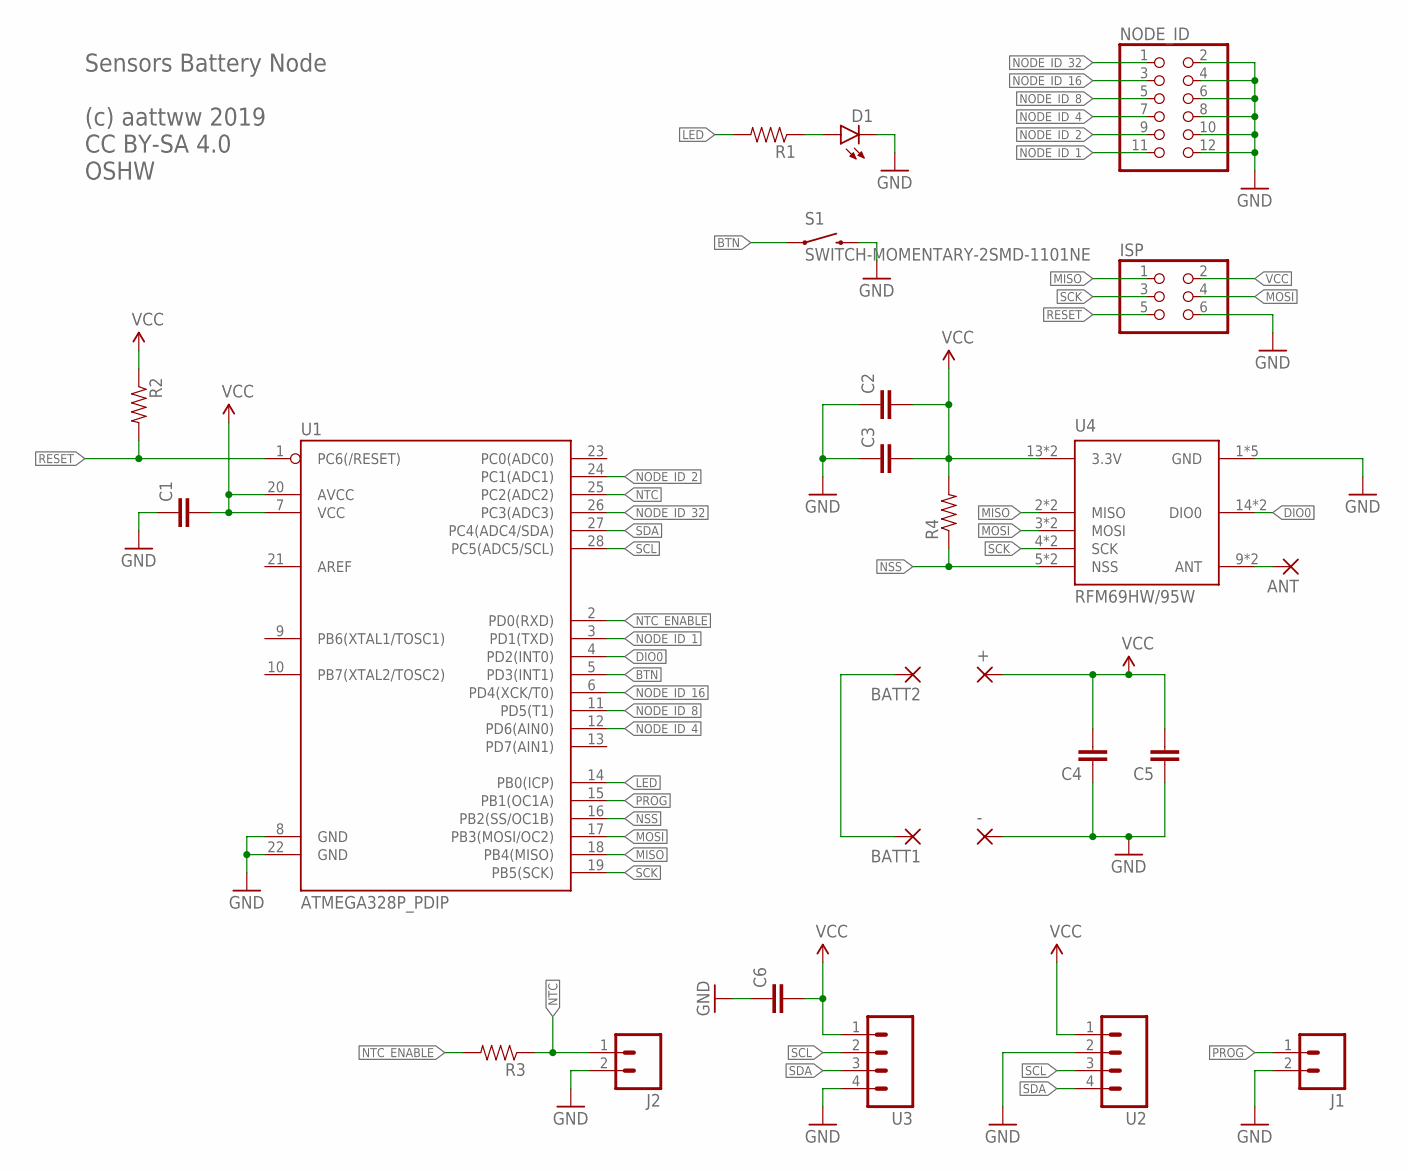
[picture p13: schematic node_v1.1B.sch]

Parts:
+: 2,15/1,0
-: 2,15/1,0
ANT: 2,15/1,0
BATT1, BATT2: 2,15/1,0
C1, C2, C3, C4, C5, C6: CAP1206; 1206
D1: LED1206; LED-1206
ISP: PINHD-2X3; 2X03
J1, J2: M02PTH; 1X02
NODE_ID: PINHD-2X6; 2X06
R1, R2, R3, R4: RESISTOR1206; 1206
S1: SWITCH-MOMENTARY-2SMD-1101NE; TACTILE-SWITCH-1101NE
U1: ATMEGA328P_PDIP; DIL28-3
U2, U3: M041X04_NO_SILK; 1X04_NO_SILK
U4: RFM69HW/95W

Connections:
BTN: S1.1, U1.5 (PD3(INT1))
DIO0: U1.4 (PD2(INT0)), U4.14 (DIO0), U4.22 (DIO0)
GND: -.1, C1.1, C2.1, C3.1, C4.1, C5.1, C6.1, D1.C, ISP.6, J1.2, J2.2, NODE_ID.2, NODE_ID.4, NODE_ID.6, NODE_ID.8, NODE_ID.10, NODE_ID.12, S1.2, U1.8 (GND), U1.22 (GND), U2.2, U3.4, U4.1 (GND), U4.8 (GND), U4.10 (GND), U4.29 (GND), U4.31 (GND)
LED: R1.2, U1.14 (PB0(ICP))
MISO: ISP.1, U1.18 (PB4(MISO)), U4.2 (MISO), U4.33 (MISO)
MOSI: ISP.4, U1.17 (PB3(MOSI/OC2)), U4.3 (MOSI), U4.34 (MOSI)
unnamed: ANT.1, U4.9 (ANT), U4.30 (ANT)
unnamed: BATT1.1, BATT2.1
unnamed: D1.A, R1.1
NODE_ID_1: NODE_ID.11, U1.3 (PD1(TXD))
NODE_ID_2: NODE_ID.9, U1.24 (PC1(ADC1))
NODE_ID_4: NODE_ID.7, U1.12 (PD6(AIN0))
NODE_ID_8: NODE_ID.5, U1.11 (PD5(T1))
NODE_ID_16: NODE_ID.3, U1.6 (PD4(XCK/T0))
NODE_ID_32: NODE_ID.1, U1.26 (PC3(ADC3))
NSS: R4.1, U1.16 (PB2(SS/OC1B)), U4.5 (NSS), U4.35 (NSS)
NTC: J2.1, R3.1, U1.25 (PC2(ADC2))
NTC_ENABLE: R3.2, U1.2 (PD0(RXD))
PROG: J1.1, U1.15 (PB1(OC1A))
RESET: ISP.5, R2.2, U1.1 (PC6(/RESET))
SCK: ISP.3, U1.19 (PB5(SCK)), U4.4 (SCK), U4.32 (SCK)
SCL: U1.28 (PC5(ADC5/SCL)), U2.3, U3.2
SDA: U1.27 (PC4(ADC4/SDA)), U2.4, U3.3
VCC: +.1, C1.2, C2.2, C3.2, C4.2, C5.2, C6.2, ISP.2, R2.1, R4.2, U1.7 (VCC), U1.20 (AVCC), U2.1, U3.1, U4.13 (3.3V), U4.28 (3.3V)

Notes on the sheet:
Sensors Battery Node (c) aattww 2019 CC BY-SA 4.0 OSHW

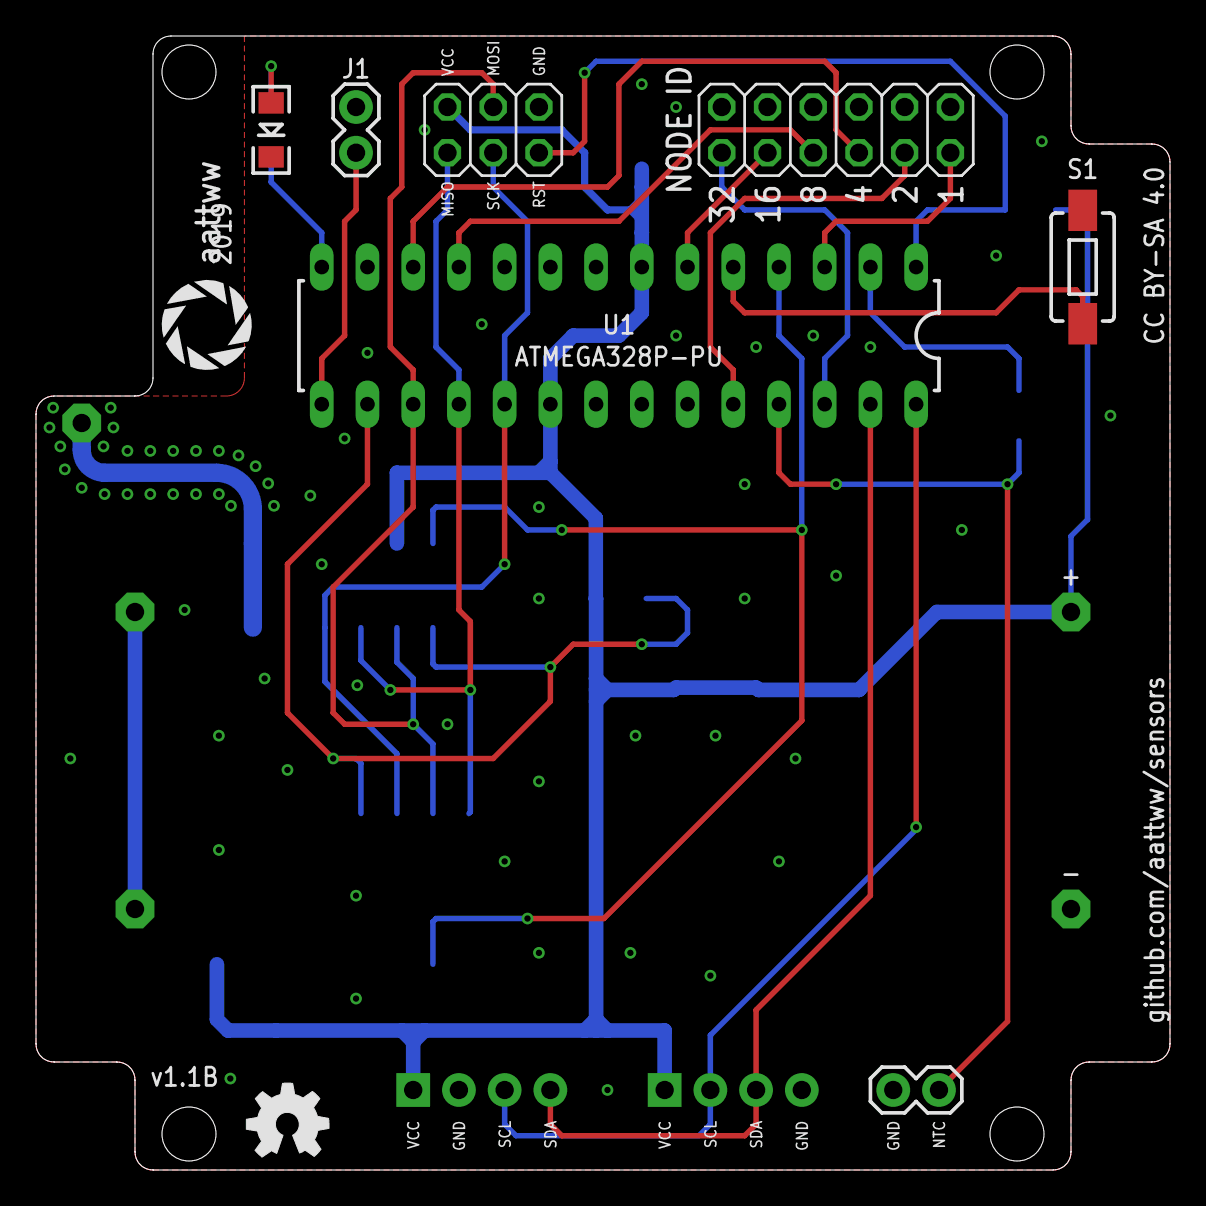
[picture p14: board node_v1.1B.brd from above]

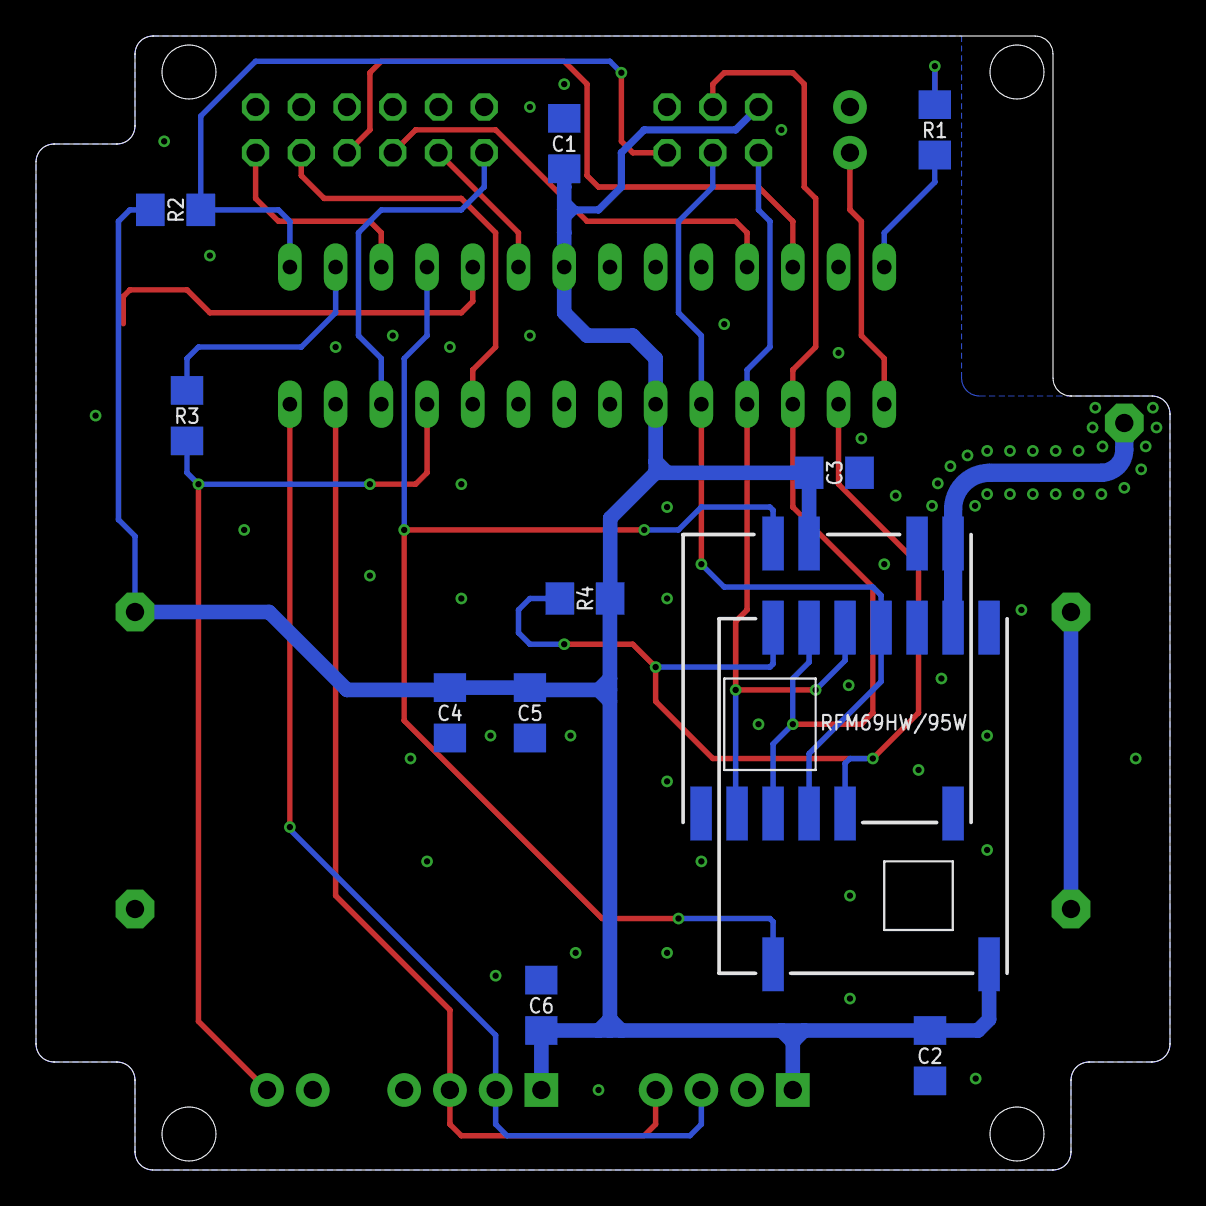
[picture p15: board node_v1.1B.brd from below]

Board: 2 copper layers, 63.0 x 63.0 mm, 27 parts (11 on the bottom side), 24 nets.

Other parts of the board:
U$1: OSHW_5MM
U$2: LOGO_5MM

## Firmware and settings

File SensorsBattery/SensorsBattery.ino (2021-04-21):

/*
 * Copyright (c) 2020 aattww (https://github.com/aattww/)
 *
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
 * You should have received a copy of the GNU General Public License
 * along with this program.  If not, see <https://www.gnu.org/licenses/>.
 */

/*
 * ######################
 * ### BEGIN SETTINGS ###
 * ######################
 */

/*
 * ### ENCRYPTION ###
 * 
 * Define whether node should use encryption. To disable encryption, comment out ENCRYPT_KEY.
 * Key must be exactly 16 characters long.
 */
#define ENCRYPT_KEY   "sample16CharKey_"

/*
 * ### LOW RATE ###
 *
 * Define whether node should use low rate transmits.
 * Low rate transmits have better range, but also increase time on air and battery usage.
 */
//#define ENABLE_LOW_RATE

/*
 * ### FREQUENCY ###
 *
 * Define radio transmit frequency in MHz.
 * Usable frequency depends on module in use and legislation.
 */
#define FREQUENCY     867.6

/*
 * ### NODE ID ###
 *
 * Optionally define ID. Normally the ID is set using headers but if you want to omit them you
 * can set the ID here. Note that if setting the ID here and programming multiple nodes, you have to
 * remember to change this setting for every node.
 *
 * Limited to 0-253. Setting to 0 will read the actual ID from the headers, setting to 1-253 will
 * use that regardless of the headers.
 */
#define NODE_ID       0

/*
 * ### RETRIES ###
 *
 * Define how many times to resend message if first transmit fails.
 * After all retries have been exhausted, new transmit is tried after sleep time.
 *
 * Limited to 0-4.
 */
#define RETRIES       1

/*
 * ### TARGET RSSI ###
 *
 * Define target RSSI for automatic power control (APC).
 * Lower value will make nodes send messages with less power, saving energy, but at the cost of
 * possibly causing more retransmits.
 *
 * -90 is a good starting point having good balance between energy usage and reliability in
 * stable environments. Decreasing to -100 and beyond gives even more energy savings but may
 * start to cause more retransmits, especially in noisy environments.
 *
 */
#define TARGET_RSSI   -90

/*
 * ### TIMINGS ###
 *
 * Define timings.
 *
 * SLEEP_TIME: How long to sleep between wake ups in seconds.
 * FORCE_SEND: How often at least should a packet be transmitted regardless of threshold in minutes.
 */
#define SLEEP_TIME    600
#define FORCE_SEND    30

/*
 * ### THRESHOLDS ###
 *
 * In threshold mode node sends new values to gateway only if they differ more than threshold from previously sent values,
 * that is: abs(new_value - previous_value) > threshold
 *
 * Note that thresholds are in tenths of value, i.e. 10 = 1.0 °C.
 * You should always set either all to zero or all to a certain value. If one threshold is zero, that will trigger send every time node wakes up (=SLEEP_TIME).
 * If you don't want certain value to affect sends, set that threshold to some large value.
 *
 * TEMPERATURE_TH: Threshold of temperature in tenths of °C (0 = send always)
 * HUMIDITY_TH: Threshold of temperature in tenths of %RH (0 = send always)
 * PRESSURE_TH: Threshold of temperature in tenths of hPa (0 = send always)
 */
#define TEMPERATURE_TH  5
#define HUMIDITY_TH     30
#define PRESSURE_TH     10

/*
 * ####################
 * ### END SETTINGS ###
 * ####################
 */


#define VERSION 4

#include <RH_RF95.h>
#include <RHDatagram.h>

#include <avr/sleep.h>
#include <avr/wdt.h>
#include <avr/power.h>

#ifdef ENCRYPT_KEY
#include <RHEncryptedDriver.h>
#include <Speck.h>
#endif

#include <Wire.h>
#include <SI7021.h>
#include <SparkFunBME280.h>
#include <NTCSensor.h>

#define MODE_NO_SENSOR  0
#define MODE_SI7021     1
#define MODE_BME280     2
#define MODE_NTC        4

#define LED_PIN         8
#define NTC_ENABLE_PIN  0
#define NTC_PIN         A2
#define BTN_PIN         3
#define JMP_PIN         9

#define PAYLOAD_LEN     11
#define MAX_PAYLOAD_LEN 40
#define GATEWAYID       254
#define TX_MAX_PWR      20
#define TX_MIN_PWR      2

const float frequency = FREQUENCY; // Radio transmit frequency (depends on module in use and legislation)
#ifdef ENCRYPT_KEY
const uint8_t encryptKey[17] = ENCRYPT_KEY; // Encryption key for communication
#endif
uint8_t maxNrOfSends = RETRIES + 1; // Maximum amount of transmits after which to give in and try again after sleepTime (1-5)
uint16_t sleepTime = SLEEP_TIME; // Sleep time between wake ups in seconds
const uint16_t forceTransmitInterval = FORCE_SEND; // How often at least should a packet be transmitted regardless of threshold (minutes)

uint16_t sensor1Threshold = TEMPERATURE_TH; // Threshold for sending sensor1 in tenths of degree C (0 = send always)
uint16_t sensor2Threshold = HUMIDITY_TH; // Threshold for sending sensor2 in tenths of RH% (0 = send always)
uint16_t sensor3Threshold = PRESSURE_TH; // Threshold for sending sensor3 in tenths of hPa (0 = send always)

// Radio and encryption instances
RH_RF95 rf95Driver;
#ifdef ENCRYPT_KEY
Speck cipherDriver;
RHEncryptedDriver encryptedDriver(rf95Driver, cipherDriver);
RHDatagram radioManager(encryptedDriver);
#else
RHDatagram radioManager(rf95Driver);
#endif

SI7021 sensorSI7021; // SI7021 instance
BME280 sensorBME280; // BME280 instance
NTCSensor sensorNTC(NTC_ENABLE_PIN, NTC_PIN); // NTC instance

// Payload buffer
// Header | Battery_MSB | Battery_LSB | TransmitPower | TransmitInterval | Sensor1_MSB | Sensor1_LSB | Sensor2_MSB | Sensor2_LSB | Sensor3_MSB | Sensor3_LSB
uint8_t payloadBuffer[MAX_PAYLOAD_LEN];

uint16_t neededSleepCycles; // How many 8 second sleep cycles are needed for full sleep time
uint8_t transmitInterval; // How often should gateway expect transmit (in minutes)
uint16_t lastTransmittedCycles; // Sleep cycles from last transmitted packet
bool previousTransmitOk = false; // Was previous transmit successful
bool hasFailedTransmit = false; // Is there at least one failed transmit (for decreasing transmit power faster after boot up)
bool isImportant = false; // When node is marked important, it triggers gateway to set external interrupt

bool isDebugMode = false;
bool isThresholdMode = false;
volatile bool forceSend = false;
uint16_t neededForceCycles; // How many sleep cycles at max between force transmits
uint8_t nodeId; // Node ID
uint8_t sensorMode = MODE_NO_SENSOR;

int16_t sensor1LastTransmittedValue = 0; // Last transmitted sensor1 value
int16_t sensor2LastTransmittedValue = 0; // Last transmitted sensor2 value
int16_t sensor3LastTransmittedValue = 0; // Last transmitted sensor3 value
int16_t sensor1Value = 0;
int16_t sensor2Value = 0;
int16_t sensor3Value = 0;

uint16_t batteryVoltage = 0;
int8_t transmitPower = ((TX_MAX_PWR - TX_MIN_PWR) / 4) + TX_MIN_PWR; // Set initial transmit power to low medium
uint8_t transmitPowerRaw = 25;
int8_t lastReportedRSSI;


void setup() {
  // LED
  pinMode(LED_PIN, OUTPUT);
  
  // Button
  pinMode(BTN_PIN, INPUT_PULLUP);
  
  // Jumper J1
  pinMode(JMP_PIN, INPUT_PULLUP);
  
  // Let inputs stabilize
  delay(10);
  
  // Enter programming mode (currently does nothing) if button is pressed. Also set debug mode.
  if (!digitalRead(BTN_PIN)) {
    enterProgMode();
    isDebugMode = true;
  }
  
  // Set node important if jumper is set
  if (!digitalRead(JMP_PIN)) {
    isImportant = true;
  }
  
  // Set pin to hi-Z to save power (otherwise jumper leaks current)
  pinMode(JMP_PIN, INPUT);
  
  // Blink led to indicate startup and fw version
  startUp();

  // Determine which sensor is connected
  // Possible options are SI7021, BME280, NTC or SI7021+NTC
  
  // Change expected BME280 address (common breakout boards use this)
  sensorBME280.setI2CAddress(0x76);
  
  // Try to initialize SI7021 sensor
  if (sensorSI7021.begin()) {
    sensorMode = MODE_SI7021;
  }
  // Try to initialize BME280 sensor if did not find SI7021
  else if (sensorBME280.beginI2C()) {
    sensorMode = MODE_BME280;
    sensorBME280.setMode(MODE_SLEEP);
  }
  // If not having BME280, try to also initialize NTC
  if ((sensorMode != MODE_BME280) && sensorNTC.init()) {
    sensorMode |= MODE_NTC;
    
    // If having SI7021+NTC, change sensor3 (now NTC) threshold to temperature instead of pressure
    if (sensorMode == (MODE_SI7021 | MODE_NTC)) {
      sensor3Threshold = TEMPERATURE_TH;
    }
  }
  
  // No valid sensor found, enter error blinking
  if (sensorMode == MODE_NO_SENSOR) {
    blinkLed(3, true);
  }
  
  // Calculate proper timings
  setTimings();

  // Read the ID if not already set
  #if NODE_ID == 0
  readIds();
  #else
  nodeId = NODE_ID;
  #endif
  
  // Initialize radio
  #ifdef ENCRYPT_KEY
  cipherDriver.setKey(encryptKey, sizeof(encryptKey)-1); // Discard null character at the end
  #endif
  radioManager.setThisAddress(nodeId);
  
  // If failed to init radio, start blinking led
  if (!radioManager.init()) {
    blinkLed(5, true);
  }
  
  rf95Driver.setFrequency(frequency);
  rf95Driver.setTxPower(transmitPower); // 5-23 dBm
  #ifdef ENABLE_LOW_RATE
  rf95Driver.setModemConfig(RH_RF95::Bw125Cr48Sf4096);
  #endif

  // Set button interrupt
  attachInterrupt(digitalPinToInterrupt(BTN_PIN), wakeUpFromBtn, FALLING);
  
  // Set force send so that message is sent after startup and led blinked
  forceSend = true;
}

void loop() {

  // Read sensor values
  if (sensorMode & MODE_SI7021) {
    readSI7021();
  }
  else if (sensorMode & MODE_BME280) {
    readBME280();
  }
  if (sensorMode & MODE_NTC) {
    readNTC();
  }

  
  // If send threshold mode is active and send is not forced...
  if (isThresholdMode && !forceSend) {
    
    // If it has been too long time from last transmit ...
    if (lastTransmittedCycles >= neededForceCycles) {
      constructAndSendPacket();
    }
    // ... or sensor value differs enough from last sent value
    else if ((abs(sensor1LastTransmittedValue - sensor1Value) > sensor1Threshold) || 
             (abs(sensor2LastTransmittedValue - sensor2Value) > sensor2Threshold) || 
             (abs(sensor3LastTransmittedValue - sensor3Value) > sensor3Threshold)) {
      constructAndSendPacket();
    }
  }
  // ... else always send
  else {
    constructAndSendPacket();
  }
  
  sleepNode();
}

bool constructAndSendPacket() {
  // Read battery voltage
  readBatteryVoltage();
  
  // Construct payload
  
  if (sensorMode == MODE_SI7021) {
    payloadBuffer[0] = B00010001;
  }
  else if (sensorMode == MODE_BME280) {
    payloadBuffer[0] = B00010100;
  }
  else if (sensorMode == MODE_NTC) {
    payloadBuffer[0] = B00010101;
  }
  else if (sensorMode == (MODE_SI7021 | MODE_NTC)) {
    payloadBuffer[0] = B00010110;
  }
  
  if (isImportant) {
    payloadBuffer[0] |= B00100000;
  }
  
  // Set expect ack bit
  payloadBuffer[0] |= B01000000;
  
  payloadBuffer[1] = batteryVoltage >> 8;
  payloadBuffer[2] = batteryVoltage;
  payloadBuffer[3] = transmitPowerRaw;
  payloadBuffer[4] = transmitInterval;
  payloadBuffer[5] = sensor1Value >> 8;
  payloadBuffer[6] = sensor1Value;
  payloadBuffer[7] = sensor2Value >> 8;
  payloadBuffer[8] = sensor2Value;
  payloadBuffer[9] = sensor3Value >> 8;
  payloadBuffer[10] = sensor3Value;

  // If in force mode, set maximum transmit power
  if (forceSend) {
    rf95Driver.setTxPower(TX_MAX_PWR);
    payloadBuffer[3] = 100;
  }
  
  bool transmitOk = false;
  for (uint8_t i = 0; i < maxNrOfSends; i++) {
    // Send packet
    transmitOk = sendPacket();
    
    // Update transmit power based on transmit result if not in force send (force sends are always sent at full power and don't count for APC)
    if (!forceSend) {
      updateTransmitPower(transmitOk);
      previousTransmitOk = transmitOk;
    }
    
    // If transmit was successful, reset and break from retransmit loop
    if (transmitOk) {
      lastTransmittedCycles = 0;
      sensor1LastTransmittedValue = sensor1Value;
      sensor2LastTransmittedValue = sensor2Value;
      sensor3LastTransmittedValue = sensor3Value;
      break;
    }
  }
  
  // Return to normal transmit power after force send
  if (forceSend) {
    rf95Driver.setTxPower(transmitPower);
    payloadBuffer[3] = transmitPowerRaw;
  }
  
  if (isDebugMode || forceSend) {
    if (transmitOk) {
      blinkLed(1, false);
    }
    else {
      blinkLed(2, false);
    }
  }
  
  forceSend = false;
  
  return transmitOk;
}

bool sendPacket() {
  // If packet accepted by radio
  if (radioManager.sendto(payloadBuffer, PAYLOAD_LEN, GATEWAYID)) {
    
    // Wait for packet to be sent
    radioManager.waitPacketSent();

    #ifdef ENABLE_LOW_RATE
    uint16_t timeout = 3500;
    #else
    uint16_t timeout = 200;
    #endif

    uint32_t sendTime = millis();

    uint8_t len = MAX_PAYLOAD_LEN;
    uint8_t from;
    uint8_t to;
    
    // Wait ack
    while ((millis() - sendTime) < timeout) {
      // If received packet from gateway
      if (radioManager.recvfrom(payloadBuffer, &len, &from, &to)) {
        if ((from == GATEWAYID) && (to == nodeId) && (len == 2)) {
          // If this really is ack
          if (payloadBuffer[0] & B00000001) {
            // Save RSSI reported by gateway for future use
            lastReportedRSSI = payloadBuffer[1];
            return true;
          }
        }
      }
    }
  }
  return false;
}

void updateTransmitPower(bool lastTransmitOk) {
  
  // Default power change. Increase to make APC more aggressive.
  int8_t defaultChange = 1;
  
  // If transmit was successful, increase/decrease power based on reported RSSI
  if (lastTransmitOk) {
    
    if (lastReportedRSSI > TARGET_RSSI) {
      // If there are no failed transmits yet, decrease power faster (to speed up power decrease after boot up)
      if (!hasFailedTransmit) {
        defaultChange *= -4;
      }
      else {
        defaultChange *= -1;
      }
    }
    else if (lastReportedRSSI < TARGET_RSSI) {
      defaultChange = defaultChange;
      
      // Not really a failed transmit but if we have to increase power, our floor has been found
      hasFailedTransmit = true;
    }
    else {
      defaultChange = 0;
    }
      
  }
  // If transmit was unsuccessful, increase always power
  else {
    hasFailedTransmit = true;
    
    // If this was the first failed transmit, increase power only by half
    if (previousTransmitOk) {
      defaultChange *= 4;
    }
    else {
      defaultChange *= 8;
    }
  }
  
  // Add/subtract change
  transmitPowerRaw = constrain((transmitPowerRaw + defaultChange), 0, 100);
  
  // Map raw transmit power to real usable range
  transmitPower = map(transmitPowerRaw, 0, 100, TX_MIN_PWR, TX_MAX_PWR);
  
  // Set radio transmit power
  rf95Driver.setTxPower(transmitPower);
  
  payloadBuffer[3] = transmitPowerRaw;
}

void sleepNode() {
  
  // Put radio to sleep
  #ifdef ENCRYPT_KEY
  encryptedDriver.sleep();
  #else
  rf95Driver.sleep();
  #endif
  
  // Make sure force send flag is cleared
  forceSend = false;
  
  // Sleep uC for sufficient number of 8 second sleep cycles
  for(uint16_t i = 0; i < neededSleepCycles; i++) {
    sleepMCU();
    lastTransmittedCycles++;
    
    // If button pressed, fall through to main loop
    if (forceSend) {
      return;
    }
  }
}

void sleepMCU() {
  // Disable ADC
  ADCSRA &= ~_BV(ADEN);

  // Set watchdog timer to 8s and interrupt only mode
  wdt_enable(WDTO_8S);
  WDTCSR |= _BV(WDIE);
  
  // Initiate actual sleep
  set_sleep_mode(SLEEP_MODE_PWR_DOWN);
  cli();
  sleep_enable();
  sleep_bod_disable();
  sei();
  sleep_cpu();
  sleep_disable();
  sei();

  // Restore ADC
  ADCSRA |= _BV(ADEN);
}

// Handle watchdog interrupt
ISR (WDT_vect) {
  // Disable watchdog for now
  wdt_disable();
}

void wakeUpFromBtn() {
  forceSend = true;
}

void setTimings() {
  // Change sleepTime to one sleep cycle if in debug mode, else use provided value
  if (isDebugMode) {
    sleepTime = 8;
  }
  
  // Calculate needed 8 second sleep cycles for full sleepTime
  neededSleepCycles = round(sleepTime / 8.0);
  if (neededSleepCycles < 1) {
    neededSleepCycles = 1;
  }
  
  // Check if we are in threshold mode
  isThresholdMode = (((sensor1Threshold > 0) || (sensor2Threshold > 0) || (sensor3Threshold > 0)) && !isDebugMode);

  // Calculate advertised transmit interval
  if (isThresholdMode) {
    transmitInterval = forceTransmitInterval;
  }
  else {
    transmitInterval = ceil(sleepTime / 60.0);
  }
  
  // Calculate needed cycles for forced transmit in threshold mode
  neededForceCycles = round(forceTransmitInterval*60 / 8.0);
  
  // Constrain maximum number of transmits value
  if (maxNrOfSends < 1) {
    maxNrOfSends = 1;
  }
  else if (maxNrOfSends > 5) {
    maxNrOfSends = 5;
  }
  
  lastTransmittedCycles = 0;
  
}

void readIds() {
  // Change correct pinmodes
  pinMode(1, INPUT_PULLUP);
  pinMode(A1, INPUT_PULLUP);
  pinMode(6, INPUT_PULLUP);
  pinMode(5, INPUT_PULLUP);
  pinMode(4, INPUT_PULLUP);
  pinMode(A3, INPUT_PULLUP);
  
  delay(5);
  
  // Read node ID
  nodeId = 0;
  bitWrite(nodeId, 0, !digitalRead(1));
  bitWrite(nodeId, 1, !digitalRead(A1));
  bitWrite(nodeId, 2, !digitalRead(6));
  bitWrite(nodeId, 3, !digitalRead(5));
  bitWrite(nodeId, 4, !digitalRead(4));
  bitWrite(nodeId, 5, !digitalRead(A3));
  
  // Change pinmodes back to INPUT to save power
  pinMode(1, INPUT);
  pinMode(A1, INPUT);
  pinMode(6, INPUT);
  pinMode(5, INPUT);
  pinMode(4, INPUT);
  pinMode(A3, INPUT);
  
  // Check for correct ids
  if ((nodeId >= 1) && (nodeId < 254)) {
    // All good
    return;
  }
  else {
    // Wrong ids set, enter error mode and start blinking led
    blinkLed(1, true);
  }
}

void readSI7021() {
  si7021_env data = sensorSI7021.getHumidityAndTemperature();
  sensor1Value = round(data.celsiusHundredths / 10.0);
  sensor2Value = round(data.humidityBasisPoints / 10.0);
}

void readBME280() {
  sensorBME280.setMode(MODE_FORCED); // Wake BME280 and start measurement
  delay(8); // According to datasheet, typical temp, hum and pressure conversion is 8ms
  
  uint32_t timeout = millis();
  while (sensorBME280.isMeasuring() && ((millis() - timeout) < 100)) { // Wait more (with timeout) if conversion is still in progress
    delay(1);
  }

  sensor1Value = round(sensorBME280.readTempC() * 10.0);
  sensor2Value = round(sensorBME280.readFloatHumidity() * 10.0);
  sensor3Value = round(sensorBME280.readFloatPressure() / 10.0);
}

void readNTC() {
  if (sensorMode == MODE_NTC) {
    sensor1Value = sensorNTC.readTemperature();
  }
  else if (sensorMode == (MODE_SI7021 | MODE_NTC)) {
    sensor3Value = sensorNTC.readTemperature();
  }
}

void readBatteryVoltage() {
  // Read 1.1V reference against AVcc
  // set the reference to Vcc and the measurement to the internal 1.1V reference
  #if defined(__AVR_ATmega32U4__) || defined(__AVR_ATmega1280__) || defined(__AVR_ATmega2560__)
    ADMUX = _BV(REFS0) | _BV(MUX4) | _BV(MUX3) | _BV(MUX2) | _BV(MUX1);
  #elif defined (__AVR_ATtiny24__) || defined(__AVR_ATtiny44__) || defined(__AVR_ATtiny84__)
    ADMUX = _BV(MUX5) | _BV(MUX0);
  #elif defined (__AVR_ATtiny25__) || defined(__AVR_ATtiny45__) || defined(__AVR_ATtiny85__)
    ADMUX = _BV(MUX3) | _BV(MUX2);
  #else
    ADMUX = _BV(REFS0) | _BV(MUX3) | _BV(MUX2) | _BV(MUX1);
  #endif  
 
  delay(2); // Wait for Vref to settle
  ADCSRA |= _BV(ADSC); // Start conversion
  while (bit_is_set(ADCSRA,ADSC)); // measuring
 
  uint8_t low  = ADCL; // must read ADCL first - it then locks ADCH  
  uint8_t high = ADCH; // unlocks both
 
  uint16_t result = 1125300L / ((high<<8) | low); // Calculate Vcc (in mV); 1125300 = 1.1*1023*1000
  
  if (batteryVoltage == 0)
    batteryVoltage = result;
  else
    batteryVoltage = (batteryVoltage * 3 + result) / 4; // Apply IIR filter to smooth voltage spikes
}

void blinkLed(uint8_t blinks, bool loop) {
  do {
    for (uint8_t i = 0; i < blinks; i++) {
      digitalWrite(LED_PIN, HIGH);
      delay(50);
      digitalWrite(LED_PIN, LOW);
      if (i != (blinks - 1)) {
        delay(150);
      }
    }
    if (loop) {
      delay(2150);
    }
  } while (loop);
}

void enterProgMode() {
  return;
}

void startUp() {
  digitalWrite(LED_PIN, HIGH);
  if (VERSION & B00001000) {
    delay(200);
  }
  else {
    delay(50);
  }
  digitalWrite(LED_PIN, LOW);
  delay(200);
  
  digitalWrite(LED_PIN, HIGH);
  if (VERSION & B00000100) {
    delay(200);
  }
  else {
    delay(50);
  }
  digitalWrite(LED_PIN, LOW);
  delay(200);
  
  digitalWrite(LED_PIN, HIGH);
  if (VERSION & B00000010) {
    delay(200);
  }
  else {
    delay(50);
  }
  digitalWrite(LED_PIN, LOW);
  delay(200);
  
  digitalWrite(LED_PIN, HIGH);
  if (VERSION & B00000001) {
    delay(200);
  }
  else {
    delay(50);
  }
  digitalWrite(LED_PIN, LOW);
  
  delay(1000);
}

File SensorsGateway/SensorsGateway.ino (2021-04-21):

/*
 * Copyright (c) 2020 aattww (https://github.com/aattww/)
 *
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
 * You should have received a copy of the GNU General Public License
 * along with this program.  If not, see <https://www.gnu.org/licenses/>.
 */

/*
 * ######################
 * ### BEGIN SETTINGS ###
 * ######################
 */

/*
 * ### ENCRYPTION ###
 *
 * Define whether node should use encryption. To disable encryption, comment out ENCRYPT_KEY.
 * Key must be exactly 16 characters long.
 */
#define ENCRYPT_KEY   "sample16CharKey_"

/*
 * ### LOW RATE ###
 *
 * Define whether node should use low rate transmits.
 * Low rate transmits have better range, but also increase time on air and battery usage.
 */
//#define ENABLE_LOW_RATE

/*
 * ### FREQUENCY ###
 *
 * Define radio transmit frequency in MHz.
 * Usable frequency depends on module in use and legislation.
 */
#define FREQUENCY     867.6

/*
 * ### MODBUS SLAVE ADDRESS ###
 *
 * Optionally define Modbus slave address. Normally the address is set using headers but if you want
 * to omit them you can set the address here.
 *
 * Limited to 0-253. Setting to 0 will read the actual address from the headers, setting to 1-253 will
 * use that regardless of the headers.
 */
#define MB_ADDRESS        0

/*
 * ### DELETE NODES ###
 *
 * Define after how many minutes delete nodes if they have not been seen.
 * Set to zero to never delete.
 */
#define DELETE_OLD_NODES  0

/*
 * ### EXTERNAL INTERRUPT ###
 *
 * Select if pulse 2 is used as an open drain active low output to inform upstream device of new messages.
 *
 * Define ENABLE_EXT_INTERRUPT if you want this feature to be enabled, otherwise comment it out.
 * Define EXT_INTERRUPT_ONLY_IMPORTANT if you want that only nodes which declare themselves as important
 * trigger external interrupt. Otherwise every new message will trigger the interrupt.
 * Define EXT_INTERRUPT_USE_INT_PULLUP to use internal (weak) Atmega328P pull-up resistor, otherwise
 * make sure to have pull-up resistor in the upstream device.
 */
//#define ENABLE_EXT_INTERRUPT
//#define EXT_INTERRUPT_ONLY_IMPORTANT
//#define EXT_INTERRUPT_USE_INT_PULLUP

/*
 * ####################
 * ### END SETTINGS ###
 * ####################
 */


#define MAJOR_VERSION 1
#define MINOR_VERSION 7

#include <SimpleModbusAsync.h>
#include <RH_RF95.h>
#include <RHDatagram.h>
#include <EEPROM.h>
#include <NTCSensor.h>
#include <SensorsMemoryHandler.h>

#ifdef ENCRYPT_KEY
#include <RHEncryptedDriver.h>
#include <Speck.h>
#endif

#define LED_PIN         A0
#define BTN_PIN         3
#define P1_PIN          6
#define P2_PIN          7
#define P3_PIN          A1
#define MAX_DE_PIN      8
#define JMP_PIN         A3
#define SRAM_NSS        9

#define GATEWAYID       254     // Gateway ID in radio network, DO NOT CHANGE!
#define TX_MAX_PWR      20      // Radio dependant, this is for RFM95
#define TX_MIN_PWR      2       // Radio dependant, this is for RFM95
#define MAX_PAYLOAD_BUF 50      // This needs to be at least 50 to be on the safe side!
#define PULSE_MIN       1000    // How many ms between pulses at least
#define EEPROM_SAVE     3600000 // How often in ms to save pulse values to EEPROM
#define MAX_NR_OF_NODES 100     // Absolute maximum number of nodes (SRAM may limit this even lower)

// Payload lengths for different nodes, DO NOT CHANGE!
#define NODE_TYPE_BATT_LENGTH    11
#define NODE_TYPE_PULSE_K_LENGTH 39
#define NODE_TYPE_PULSE_LENGTH   15

/* ### SETTINGS ### */
const float frequency = FREQUENCY; // Radio transmit frequency (depends on module in use and legislation)
#ifdef ENCRYPT_KEY
const uint8_t encryptKey[17] = ENCRYPT_KEY; // Encryption key for communication
#endif
const uint16_t deleteOldNodes = DELETE_OLD_NODES; // After how many minutes delete nodes not seen (0 = never delete)
/* ### END SETTINGS ### */


// Radio and encryption instances
RH_RF95 rf95Driver;
#ifdef ENCRYPT_KEY
Speck cipherDriver;
RHEncryptedDriver encryptedDriver(rf95Driver, cipherDriver);
RHDatagram radioManager(encryptedDriver);
#else
RHDatagram radioManager(rf95Driver);
#endif

// Modbus handler instance
SimpleModbusAsync modbus;

// NTC instance
NTCSensor sensorNTC(NTC_NO_ENABLE_PIN, P3_PIN);

// Memory handler instance
SensorsMemoryHandler memoryHandler(SRAM_NSS);

// Struct to hold gateway metadata
struct {
  uint16_t errors;
  uint16_t overflownFrames;
  uint16_t illegalFunctionReads;
  uint16_t illegalAddressReads;
  uint16_t framesReceived;
  uint16_t framesSent;
  uint8_t nodesDuringLastHour;
  uint8_t nodesDuringLast12Hours;
  uint8_t nodesDuringLast24Hours;
  bool lowBatteryVoltage;
  uint16_t version;
  volatile uint32_t pulse1;
  volatile uint32_t pulse2;
  volatile uint32_t pulse3;
  bool outOfMemory;
  uint16_t uptime;
  uint8_t lastRcvdNode;
} gwMetaData;

// Various variables
uint8_t nodeId; // Node ID for Modbus
uint8_t payloadBuffer[MAX_PAYLOAD_BUF];
uint8_t blinkMode = 0;
uint32_t blinkUpdated = 0;
bool hasNTC;
volatile uint32_t pulse1LastFall = 0;
volatile uint32_t pulse2LastFall = 0;
volatile uint32_t pulse3LastFall = 0;
volatile bool pulse1LastValue = true;
volatile bool pulse2LastValue = true;
volatile bool pulse3LastValue = true;
uint32_t lastSaveToEEPROM = 0;
uint32_t lastReceivedUpdated = 0;
uint8_t millisOverflows = 0;
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

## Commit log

2019-12-26 Initial release
    [AP9_holder.stl, gateway_v1.2A.brd, gateway_v1.2A.sch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]
2019-12-29 Fix NTCSensor enable pin bug (#1)
    * Fix NTC enable pin bug
    Do not change any pinmodes or values if enablePin is not in use when reading temperature.
    * Add version history
    * Update README.md
    [SensorsGateway.ino, SensorsPulse.ino]
2020-02-03 Fix overflow bug in gateway uptime calculation
    [SensorsGateway.ino]
2020-02-03 Add image of wired Si7021 breakout board for outdoor sensor use
2020-02-15 Add interrupt pin to gateway
    Adds:
    * External interrupt to gateway.
    * ID of the last received node to gateway Modbus registers.
    * Importance setting to battery/pulse nodes.
    Refines and updates readme with regards to previous points. Also has some general cleaning and clarification of readme.
2020-03-21 Refine sensor reading and calculations
2020-04-23 Fix transaction handling
    Use beginTransaction() and endTransaction() to prevent interrupts corrupting data. Also use transfer() instead of transfer16() to write register address. Closes #8
2020-06-07 Fix transmit powers
2020-06-07 Update README, add image of water temperature node
2020-10-16 Fixes, initial working version
    [SensorsBattery.ino, SensorsPulse.ino]
2021-02-01 Update topology for new footprints

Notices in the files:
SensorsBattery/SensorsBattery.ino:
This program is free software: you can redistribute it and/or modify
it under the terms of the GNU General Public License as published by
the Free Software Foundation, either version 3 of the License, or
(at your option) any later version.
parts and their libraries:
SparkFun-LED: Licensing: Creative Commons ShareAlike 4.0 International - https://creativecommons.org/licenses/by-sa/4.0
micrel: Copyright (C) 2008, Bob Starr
